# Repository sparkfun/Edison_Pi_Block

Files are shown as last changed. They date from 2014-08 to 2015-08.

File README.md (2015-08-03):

SparkFun Edison Pi Block
========================

SparkFun Edison Pi Block

[*SparkFun Edison Pi Block (DEV-13044)*](https://www.sparkfun.com/products/13044)

The Pi Block is a simple breakout board to bring the GPIO from the Intel Edison to the user. The Block provides level-shifted access to basic GPIO, PWM, UART, I<sup>2</sup>C, and SPI. The pins are presented in the same configuration as a [Raspberry Pi Model B header](http://elinux.org/RPi_Low-level_peripherals#Model_A_and_B_.28Original.29).

Access to the GPIO pins can be accomplished through [MRAA](https://github.com/intel-iot-devkit/mraa). The GPIO number listed on the board or Linux is not the same as MRAA. Refer to the table to see which GPIO pin maps to which number in MRAA. 

*MRAA pin map table based on [Intel's IOT Dev Kit Repository](https://github.com/intel-iot-devkit/mraa/blob/master/docs/edison.md)*

*Pins on the Pi Block are denoted with a * after the GP number*

<table class="table table-bordered">
<thead><tr><th class="text-center" title="Field #1">Edison Pin (Linux)</th>
<th class="text-center" title="Field #2">Arduino Breakout</th>
<th class="text-center" title="Field #3">Mini Breakout</th>
<th class="text-center" title="Field #4">MRAA Number</th>
<th class="text-center" title="Field #5">Pinmode0</th>
<th class="text-center" title="Field #6">Pinmode1</th>
<th class="text-center" title="Field #7">Pinmode2</th>
</tr></thead>
<tbody><tr class="warning" align="center"><td>GP12*</td>
<td>3</td>
<td>J18-7 </td>
<td align="right">20</td>
<td>GPIO-12</td>
<td>PWM0</td>
<td> </td>
</tr>
<tr class="warning" align="center"><td>GP13*</td>
<td>5</td>
<td>J18-1 </td>
<td align="right">14</td>
<td>GPIO-13</td>
<td>PWM1</td>
<td> </td>
</tr>
<tr class="warning" align="center"><td>GP14*</td>
<td>A4</td>
<td>J19-9 </td>
<td align="right">36</td>
<td>GPIO-14</td>
<td> </td>
<td> </td>
</tr>
<tr align="center"><td>GP15</td>
<td> </td>
<td>J20-7 </td>
<td align="right">48</td>
<td>GPIO-15</td>
<td> </td>
<td> </td>
</tr>
<tr class="warning" align="center"><td>GP19*</td>
<td> </td>
<td>J18-6 </td>
<td align="right">19</td>
<td>GPIO-19</td>
<td>I2C-1-SCL</td>
<td> </td>
</tr>
<tr class="warning" align="center"><td>GP20*</td>
<td> </td>
<td>J17-8 </td>
<td align="right">7</td>
<td>GPIO-20</td>
<td>I2C-1-SDA</td>
<td> </td>
</tr>
<tr align="center"><td>GP27</td>
<td> </td>
<td>J17-7 </td>
<td align="right">6</td>
<td>GPIO-27</td>
<td>I2C-6-SCL</td>
<td> </td>
</tr>
<tr align="center"><td>GP28</td>
<td> </td>
<td>J17-9 </td>
<td align="right">8</td>
<td>GPIO-28</td>
<td>I2C-6-SDA</td>
<td> </td>
</tr>
<tr align="center"><td>GP40</td>
<td>13</td>
<td>J19-10 </td>
<td align="right">37</td>
<td>GPIO-40</td>
<td>SSP2_CLK</td>
<td> </td>
</tr>
<tr align="center"><td>GP41</td>
<td>10</td>
<td>J20-10 </td>
<td align="right">51</td>
<td>GPIO-41</td>
<td>SSP2_FS</td>
<td> </td>
</tr>
<tr align="center"><td>GP42</td>
<td>12</td>
<td>J20-9 </td>
<td align="right">50</td>
<td>GPIO-42</td>
<td>SSP2_RXD</td>
<td> </td>
</tr>
<tr align="center"><td>GP43</td>
<td>11</td>
<td>J19-11 </td>
<td align="right">38</td>
<td>GPIO-43</td>
<td>SSP2_TXD</td>
<td> </td>
</tr>
<tr class="warning" align="center"><td>GP44*</td>
<td>A0</td>
<td>J19-4 </td>
<td align="right">31</td>
<td>GPIO-44</td>
<td> </td>
<td> </td>
</tr>
<tr class="warning" align="center"><td>GP45*</td>
<td>A1</td>
<td>J20-4 </td>
<td align="right">45</td>
<td>GPIO-45</td>
<td> </td>
<td> </td>
</tr>
<tr class="warning" align="center"><td>GP46*</td>
<td>A2</td>
<td>J19-5 </td>
<td align="right">32</td>
<td>GPIO-46</td>
<td> </td>
<td> </td>
</tr>
<tr class="warning" align="center"><td>GP47*</td>
<td>A3</td>
<td>J20-5 </td>
<td align="right">46</td>
<td>GPIO-47</td>
<td> </td>
<td> </td>
</tr>
<tr class="warning" align="center"><td>GP48*</td>
<td>7</td>
<td>J19-6 </td>
<td align="right">33</td>
<td>GPIO-48</td>
<td> </td>
<td> </td>
</tr>
<tr align="center"><td>GP49</td>
<td>8</td>
<td>J20-6 </td>
<td align="right">47</td>
<td>GPIO-49</td>
<td> </td>
<td> </td>
</tr>
<tr align="center"><td>GP77</td>
<td> </td>
<td>J19-12 </td>
<td align="right">39</td>
<td>GPIO-77</td>
<td>SD</td>
<td> </td>
</tr>
<tr align="center"><td>GP78</td>
<td> </td>
<td>J20-11 </td>
<td align="right">52</td>
<td>GPIO-78</td>
<td>SD</td>
<td> </td>
</tr>
<tr align="center"><td>GP79</td>
<td> </td>
<td>J20-12 </td>
<td align="right">53</td>
<td>GPIO-79</td>
<td>SD</td>
<td> </td>
</tr>
<tr align="center"><td>GP80</td>
<td> </td>
<td>J20-13 </td>
<td align="right">54</td>
<td>GPIO-80</td>
<td>SD</td>
<td> </td>
</tr>
<tr align="center"><td>GP81</td>
<td> </td>
<td>J20-14 </td>
<td align="right">55</td>
<td>GPIO-81</td>
<td>SD</td>
<td> </td>
</tr>
<tr align="center"><td>GP82</td>
<td> </td>
<td>J19-13 </td>
<td align="right">40</td>
<td>GPIO-82</td>
<td>SD</td>
<td> </td>
</tr>
<tr align="center"><td>GP83</td>
<td> </td>
<td>J19-14 </td>
<td align="right">41</td>
<td>GPIO-83</td>
<td>SD</td>
<td> </td>
</tr>
<tr align="center"><td>GP84</td>
<td> </td>
<td>J20-8 </td>
<td align="right">49</td>
<td>GPIO-84</td>
<td>SD</td>
<td> </td>
</tr>
<tr class="warning" align="center"><td>GP109*</td>
<td> </td>
<td>J17-11 </td>
<td align="right">10</td>
<td>GPIO-109</td>
<td>SPI-5-SCK</td>
<td> </td>
</tr>
<tr class="warning" align="center"><td>GP110*</td>
<td> </td>
<td>J18-10 </td>
<td align="right">23</td>
<td>GPIO-110</td>
<td>SPI-5-CS0</td>
<td> </td>
</tr>
<tr class="warning" align="center"><td>GP111*</td>
<td> </td>
<td>J17-10 </td>
<td align="right">9</td>
<td>GPIO-111</td>
<td>SPI-5-CS1</td>
<td> </td>
</tr>
<tr class="warning" align="center"><td>GP114*</td>
<td> </td>
<td>J18-11 </td>
<td align="right">24</td>
<td>GPIO-114</td>
<td>SPI-5-MISO</td>
<td> </td>
</tr>
<tr class="warning" align="center"><td>GP115*</td>
<td> </td>
<td>J17-12 </td>
<td align="right">11</td>
<td>GPIO-115</td>
<td>SPI-5-MOSI</td>
<td> </td>
</tr>
<tr align="center"><td>GP128</td>
<td>2</td>
<td>J17-14 </td>
<td align="right">13</td>
<td>GPIO-128</td>
<td>UART-1-CTS</td>
<td> </td>
</tr>
<tr align="center"><td>GP129</td>
<td>4</td>
<td>J18-12 </td>
<td align="right">25</td>
<td>GPIO-129</td>
<td>UART-1-RTS</td>
<td> </td>
</tr>
<tr class="warning" align="center"><td>GP130*</td>
<td>0</td>
<td>J18-13 </td>
<td align="right">26</td>
<td>GPIO-130</td>
<td>UART-1-RX</td>
<td> </td>
</tr>
<tr class="warning" align="center"><td>GP131*</td>
<td>1</td>
<td>J19-8 </td>
<td align="right">35</td>
<td>GPIO-131</td>
<td>UART-1-TX</td>
<td> </td>
</tr>
<tr align="center"><td>GP134</td>
<td> </td>
<td>J20-3 </td>
<td align="right">44</td>
<td> </td>
<td> </td>
<td> </td>
</tr>
<tr align="center"><td>GP135</td>
<td> </td>
<td>J17-5 </td>
<td align="right">4</td>
<td>GPIO-135</td>
<td>UART</td>
<td> </td>
</tr>
<tr align="center"><td>GP165</td>
<td>A5</td>
<td>J18-2 </td>
<td align="right">15</td>
<td>GPIO-165</td>
<td> </td>
<td> </td>
</tr>
<tr align="center"><td>GP182</td>
<td>6</td>
<td>J17-1 </td>
<td align="right">0</td>
<td>GPIO-182</td>
<td>PWM2</td>
<td> </td>
</tr>
<tr align="center"><td>GP183</td>
<td>9</td>
<td>J18-8 </td>
<td align="right">21</td>
<td>GPIO-183</td>
<td>PWM3</td>
<td> </td>
</tr>
</tbody></table>

Repository Contents
-------------------
* **/Hardware** - Eagle PCB layout files
* **/Production** - Files to support SparkFun production

Documentation
--------------
* **[Hookup Guide](https://learn.sparkfun.com/tutorials/sparkfun-blocks-for-intel-edison---pi-block)** - Basic hookup guide

Product Versions
----------------
* [DEV-13044](https://www.sparkfun.com/products/13038)- Hardware version 1.0. 

Version History
---------------
* [V_1.0](https://github.com/sparkfun/Edison_Pi_Block/tree/V_1.0) - GitHub files version 1.0

License Information
-------------------

This product is _**open source**_! 

Please review the LICENSE.md file for license information. 

If you have any questions or concerns on licensing, please contact techsupport@sparkfun.com.

Distributed as-is; no warranty is given.

- Your friends at SparkFun.

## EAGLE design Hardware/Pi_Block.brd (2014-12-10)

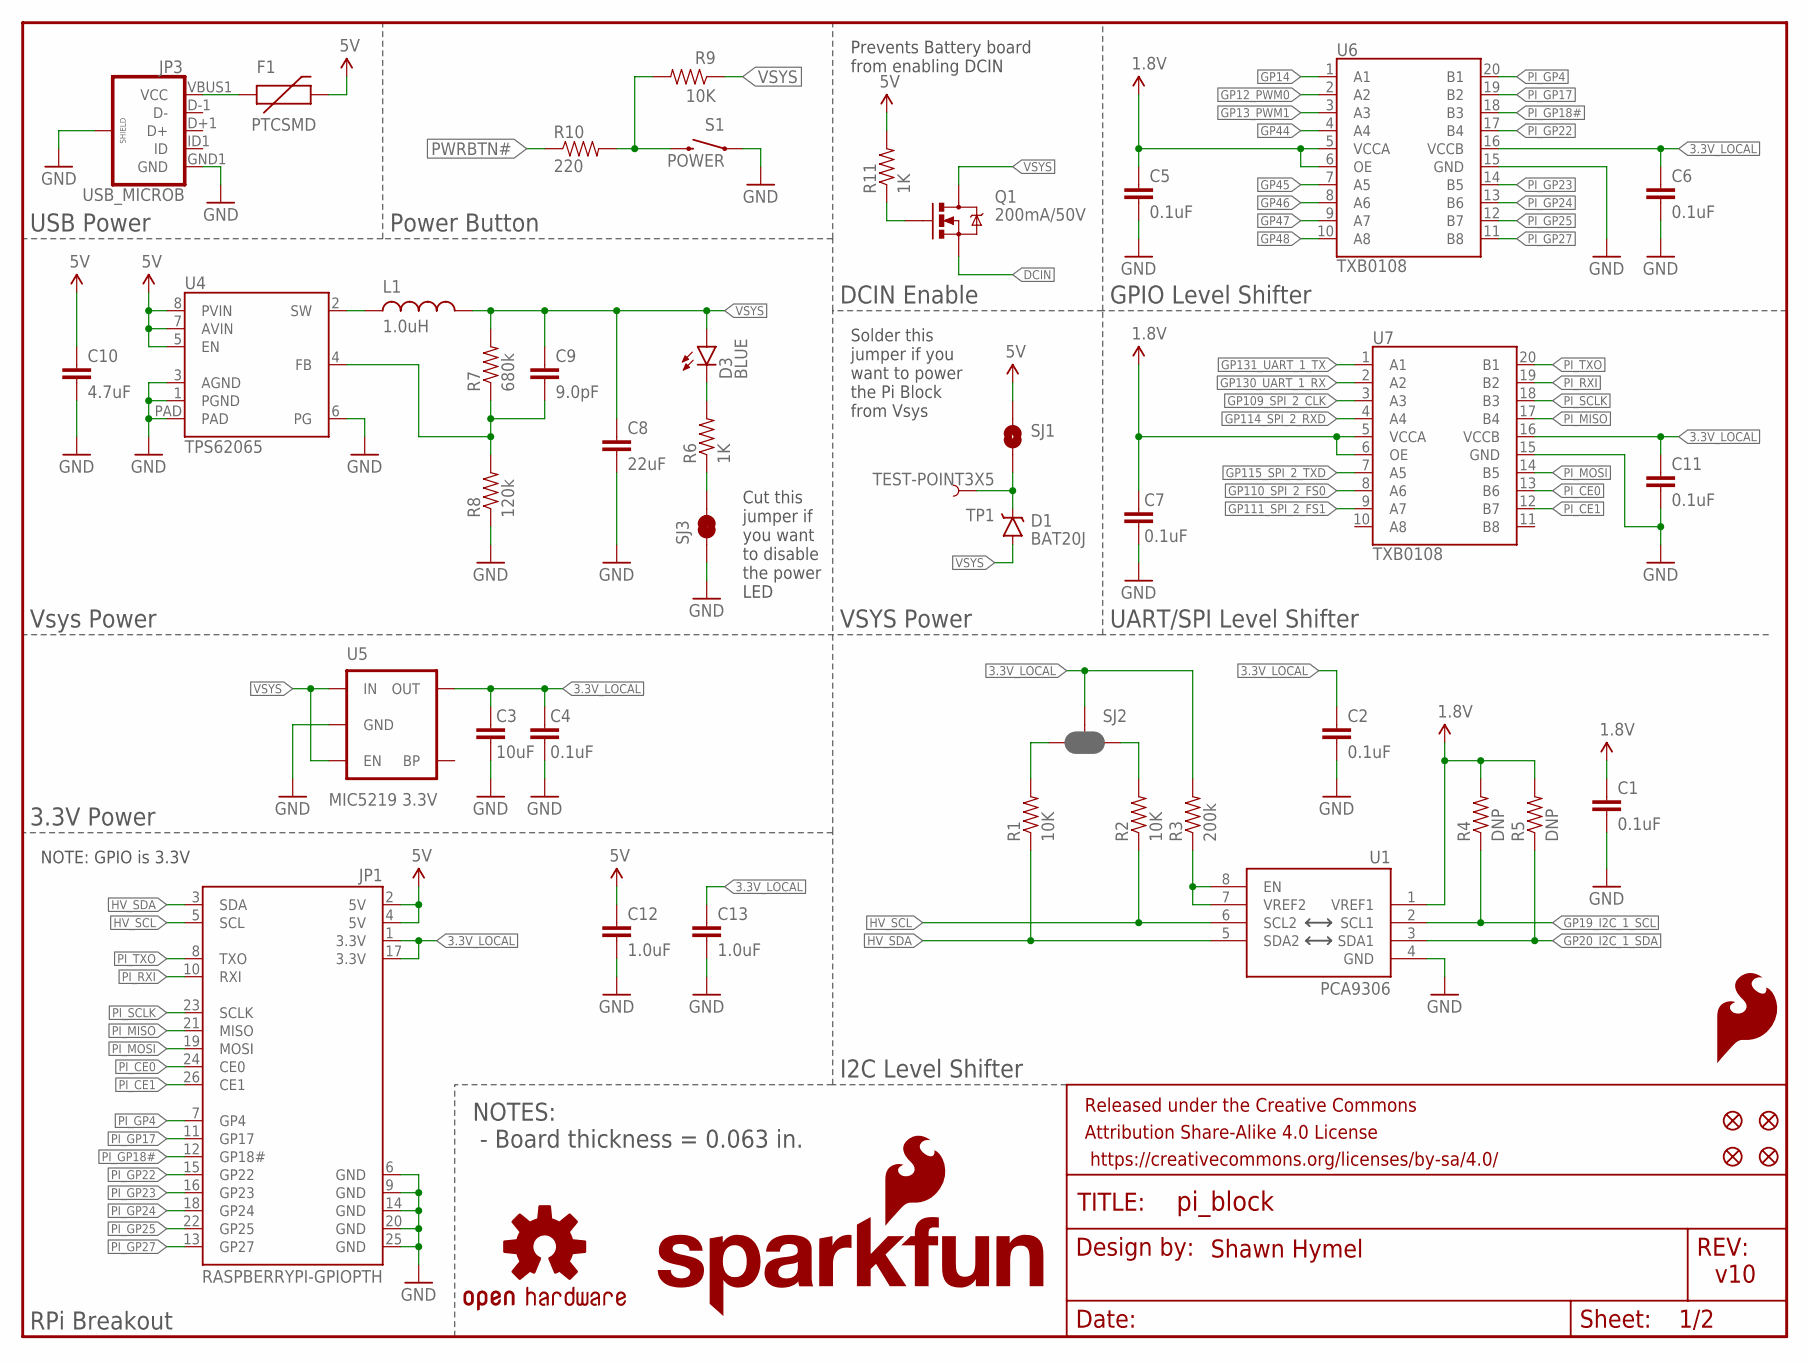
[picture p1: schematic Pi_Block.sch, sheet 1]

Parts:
C1, C2, C4, C5, C6, C7, C11: 0.1uF; 0603-CAP
C3: 10uF; 0805
C8: 22uF; 0805
C9: 9.0pF; 0603-CAP
C10: 4.7uF; 0603-CAP
C12, C13: 1.0uF; 0603-CAP
D1: BAT20J; SOD-323
D3: BLUE; LED-0603
F1: PTCSMD; PTC-1206
FID1, FID2, FID3, FID4: FIDUCIAL1X2; FIDUCIAL-1X2
FRAME1, FRAME3: FRAME-LETTER; CREATIVE_COMMONS
JP1: RASPBERRYPI-GPIOPTH; 2X13-SHROUDED
JP3: USB_MICROB; USB-B-MICRO-SMD_V03
L1: 1.0uH; INDUCTOR-SRP4020
LOGO1: OSHW-LOGOS; OSHW-LOGO-S
LOGO3: SFE_LOGO_FLAME.2_INCH; SFE_LOGO_FLAME_.2
LOGO4: SFE_LOGO_NAME_FLAME.1_INCH; SFE_LOGO_NAME_FLAME_.1
Q1: 200mA/50V; SOT23-3
R1, R2, R9: 10K; 0603-RES
R3: 200k; 0603-RES
R4, R5: DNP; 0603-RES
R6, R11: 1K; 0603-RES
R7: 680k; 0603-RES
R8: 120k; 0603-RES
R10: 220; 0603-RES
S1: POWER; TACTILE_SWITCH-SMD-RIGHT-ANGLE
SJ1: JUMPER-PAD-2-NOYES_SILK; PAD-JUMPER-2-NO_YES_SILK
SJ2: JUMPER-PAD-3-NC_BY_PASTE; PAD-JUMPER-3-NC_BY_PASTE_YES_SILK_FULL_BOX
SJ3: JUMPER-PAD-2-NC_BY_TRACE; PAD-JUMPER-2-NC_BY_TRACE_YES_SILK
TP1: TEST-POINT3X5; PAD.03X.05
U1: PCA9306; PCA9306DC-1:1
U4: TPS62065; WSON-8-PAD
U5: MIC5219 3.3V; SOT23-5
U6, U7: TXB0108; UFDFN-20

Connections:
1.8V: C1.1, C5.1, C7.1, R4.2, R5.2, U1.1 (VREF1), U6.5 (VCCA), U6.6 (OE), U7.5 (VCCA), U7.6 (OE); also elsewhere on the board
3.3V_LOCAL: C2.1, C3.1, C4.1, C6.1, C11.1, C13.1, JP1.1 (3.3V), JP1.17 (3.3V), R3.2, SJ2.2, U5.5 (OUT), U6.16 (VCCB), U7.16 (VCCB)
5V: C10.1, C12.1, F1.2, JP1.2 (5V), JP1.4 (5V), R11.2, SJ1.1, U4.5 (EN), U4.7 (AVIN), U4.8 (PVIN)
DCIN: Q1.2 (S); also elsewhere on the board
GND: C1.2, C2.2, C3.2, C4.2, C5.2, C6.2, C7.2, C8.2, C10.2, C11.2, C12.2, C13.2, JP1.6 (GND), JP1.9 (GND), JP1.14 (GND), JP1.20 (GND), JP1.25 (GND), JP3.GND1 (GND), JP3.SHIELD1 (SHIELD), JP3.SHIELD2 (SHIELD), JP3.SHIELD3 (SHIELD), R8.1, S1.1, SJ3.1, U1.4 (GND), U4.1 (PGND), U4.3 (AGND), U4.6 (PG), U4.PAD, U5.2 (GND), U6.15 (GND), U7.15 (GND); also elsewhere on the board
GP12_PWM0: U6.2 (A2); also elsewhere on the board
GP13_PWM1: U6.3 (A3); also elsewhere on the board
GP14: U6.1 (A1); also elsewhere on the board
GP19_I2C_1_SCL: R4.1, U1.2 (SCL1); also elsewhere on the board
GP20_I2C_1_SDA: R5.1, U1.3 (SDA1); also elsewhere on the board
GP44: U6.4 (A4); also elsewhere on the board
GP45: U6.7 (A5); also elsewhere on the board
GP46: U6.8 (A6); also elsewhere on the board
GP47: U6.9 (A7); also elsewhere on the board
GP48: U6.10 (A8); also elsewhere on the board
GP109_SPI_2_CLK: U7.3 (A3); also elsewhere on the board
GP110_SPI_2_FS0: U7.8 (A6); also elsewhere on the board
GP111_SPI_2_FS1: U7.9 (A7); also elsewhere on the board
GP114_SPI_2_RXD: U7.4 (A4); also elsewhere on the board
GP115_SPI_2_TXD: U7.7 (A5); also elsewhere on the board
GP130_UART_1_RX: U7.2 (A2); also elsewhere on the board
GP131_UART_1_TX: U7.1 (A1); also elsewhere on the board
HV_SCL: JP1.5 (SCL), R2.1, U1.6 (SCL2)
HV_SDA: JP1.3 (SDA), R1.1, U1.5 (SDA2)
unnamed: R3.1, U1.7 (VREF2), U1.8 (EN)
unnamed: F1.1, JP3.VBUS1 (VCC)
unnamed: D1.C, SJ1.2, TP1.P$1
unnamed: R1.2, SJ2.3
unnamed: R2.2, SJ2.1
unnamed: D3.C, R6.2
unnamed: R6.1, SJ3.2
unnamed: R9.2, R10.2, S1.2
unnamed: Q1.1 (G), R11.1
unnamed: C9.2, R7.1, R8.2, U4.4 (FB)
unnamed: L1.P$1 (1), U4.2 (SW)
PI_CE0: JP1.24 (CE0), U7.13 (B6)
PI_CE1: JP1.26 (CE1), U7.12 (B7)
PI_GP4: JP1.7 (GP4), U6.20 (B1)
PI_GP17: JP1.11 (GP17), U6.19 (B2)
PI_GP18#: JP1.12 (GP18#), U6.18 (B3)
PI_GP22: JP1.15 (GP22), U6.17 (B4)
PI_GP23: JP1.16 (GP23), U6.14 (B5)
PI_GP24: JP1.18 (GP24), U6.13 (B6)
PI_GP25: JP1.22 (GP25), U6.12 (B7)
PI_GP27: JP1.13 (GP27), U6.11 (B8)
PI_MISO: JP1.21 (MISO), U7.17 (B4)
PI_MOSI: JP1.19 (MOSI), U7.14 (B5)
PI_RXI: JP1.10 (RXI), U7.19 (B2)
PI_SCLK: JP1.23 (SCLK), U7.18 (B3)
PI_TXO: JP1.8 (TXO), U7.20 (B1)
PWRBTN#: R10.1; also elsewhere on the board
VSYS: C8.1, C9.1, D1.A, D3.A, L1.P$2 (2), Q1.3 (D), R7.2, R9.1, U5.1 (IN), U5.3 (EN); also elsewhere on the board

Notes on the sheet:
v10
Shawn Hymel
USB Power
Vsys Power
3.3V Power
RPi Breakout
GPIO Level Shifter
UART/SPI Level Shifter
I2C Level Shifter
Power Button
Prevents Battery board from enabling DCIN
DCIN Enable
VSYS Power
Solder this jumper if you want to power the Pi Block from Vsys
Cut this jumper if you want to disable the power LED
NOTE: GPIO is 3.3V
NOTES: - Board thickness = 0.063 in.

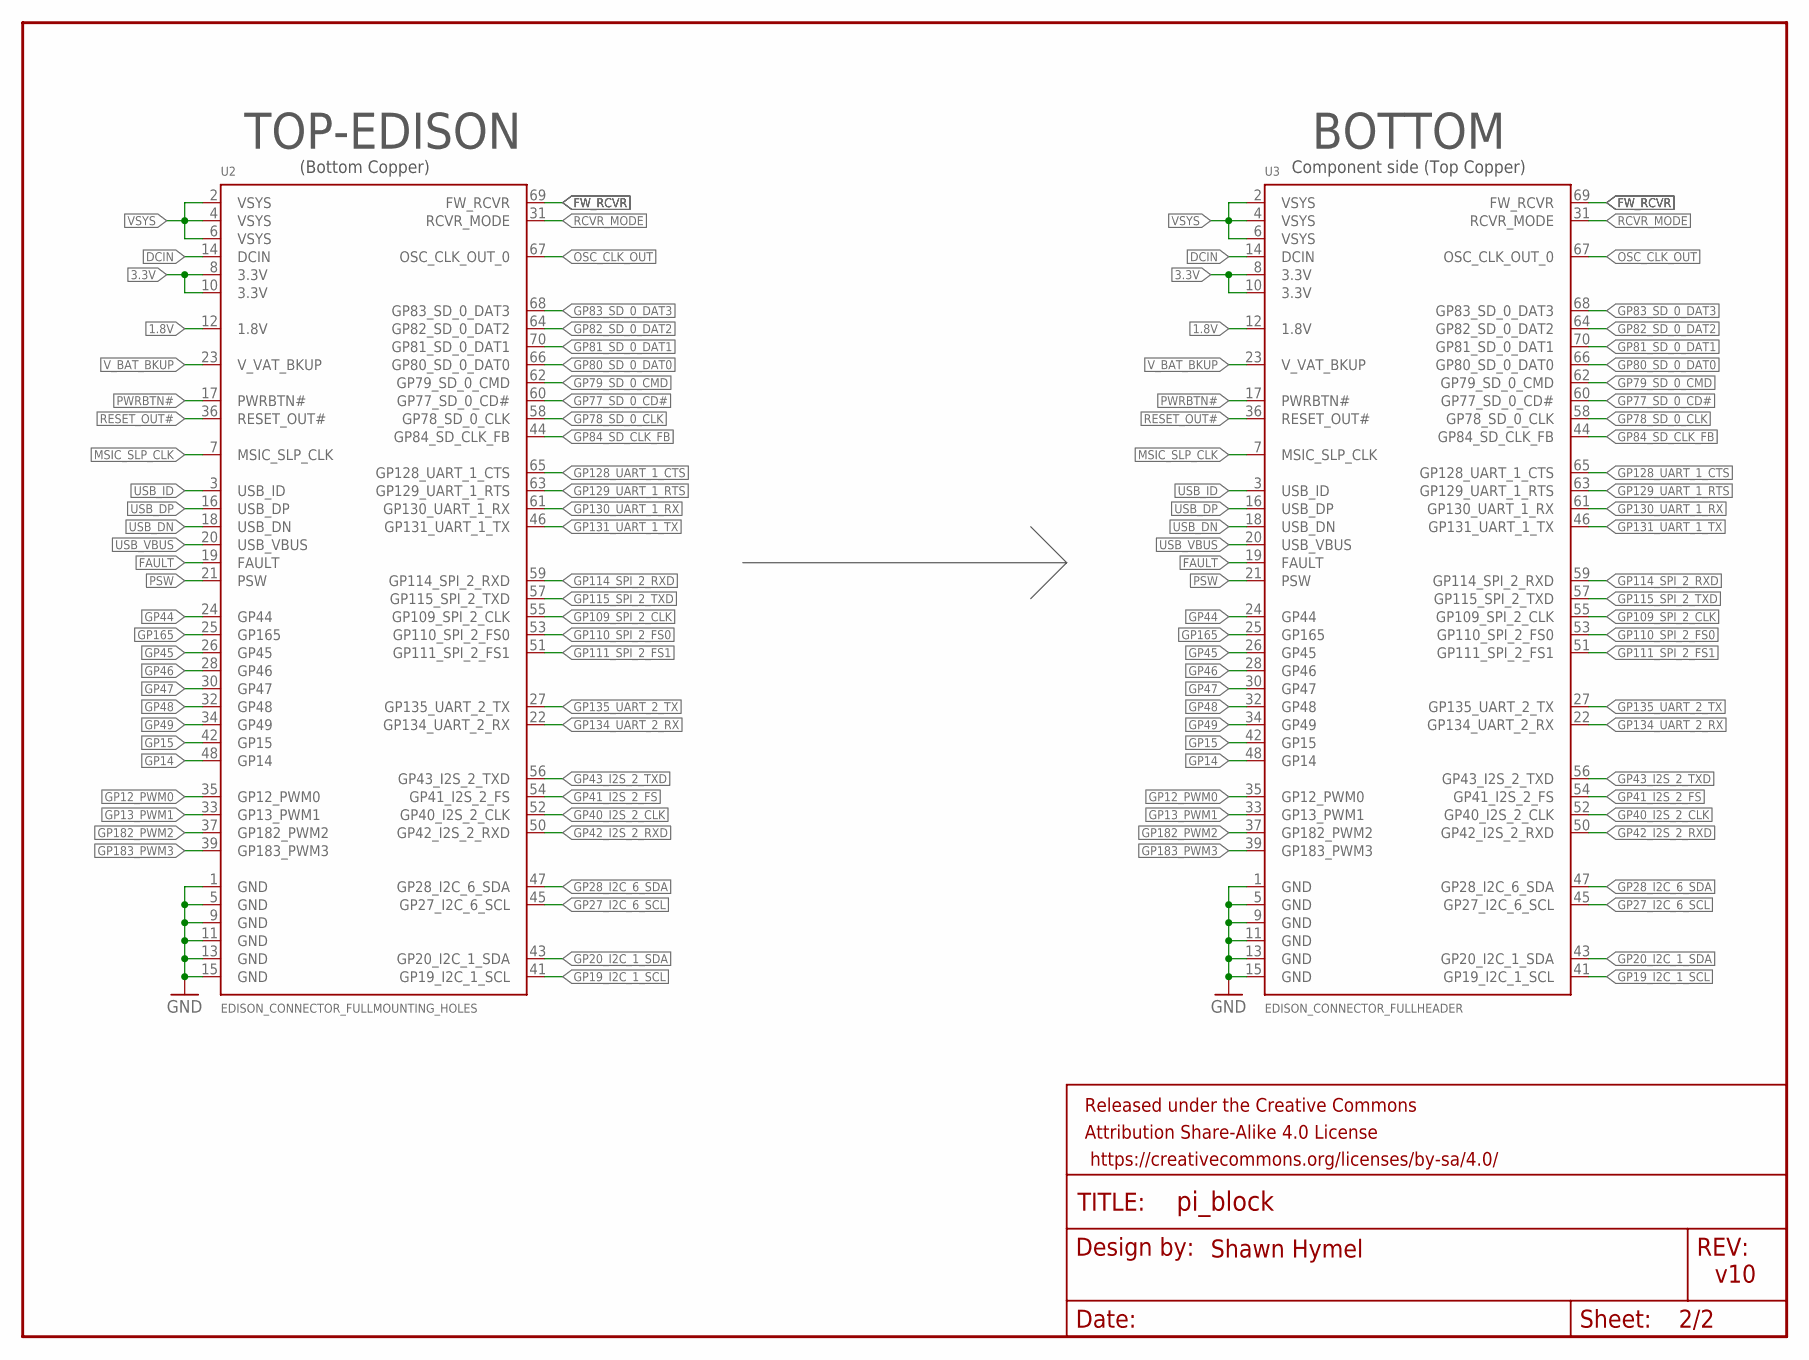
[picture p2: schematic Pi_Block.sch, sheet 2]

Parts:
FRAME2: FRAME-LETTER; CREATIVE_COMMONS
U2: EDISON_CONNECTOR_FULLMOUNTING_HOLES; EDISON_DAUGHTER
U3: EDISON_CONNECTOR_FULLHEADER; DF40C-70DP-0.4(51)

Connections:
1.8V: U2.12 (1.8V), U3.12 (1.8V); also elsewhere on the board
3.3V: U2.8 (3.3V), U2.10 (3.3V), U3.8 (3.3V), U3.10 (3.3V)
DCIN: U2.14 (DCIN), U3.14 (DCIN); also elsewhere on the board
FAULT: U2.19 (FAULT), U3.19 (FAULT)
FW_RCVR: U2.69 (FW_RCVR), U3.69 (FW_RCVR)
GND: U2.1 (GND), U2.5 (GND), U2.9 (GND), U2.11 (GND), U2.13 (GND), U2.15 (GND), U3.1 (GND), U3.5 (GND), U3.9 (GND), U3.11 (GND), U3.13 (GND), U3.15 (GND); also elsewhere on the board
GP12_PWM0: U2.35 (GP12_PWM0), U3.35 (GP12_PWM0); also elsewhere on the board
GP13_PWM1: U2.33 (GP13_PWM1), U3.33 (GP13_PWM1); also elsewhere on the board
GP14: U2.48 (GP14), U3.48 (GP14); also elsewhere on the board
GP15: U2.42 (GP15), U3.42 (GP15)
GP19_I2C_1_SCL: U2.41 (GP19_I2C_1_SCL), U3.41 (GP19_I2C_1_SCL); also elsewhere on the board
GP20_I2C_1_SDA: U2.43 (GP20_I2C_1_SDA), U3.43 (GP20_I2C_1_SDA); also elsewhere on the board
GP27_I2C_6_SCL: U2.45 (GP27_I2C_6_SCL), U3.45 (GP27_I2C_6_SCL)
GP28_I2C_6_SDA: U2.47 (GP28_I2C_6_SDA), U3.47 (GP28_I2C_6_SDA)
GP40_I2S_2_CLK: U2.52 (GP40_I2S_2_CLK), U3.52 (GP40_I2S_2_CLK)
GP41_I2S_2_FS: U2.54 (GP41_I2S_2_FS), U3.54 (GP41_I2S_2_FS)
GP42_I2S_2_RXD: U2.50 (GP42_I2S_2_RXD), U3.50 (GP42_I2S_2_RXD)
GP43_I2S_2_TXD: U2.56 (GP43_I2S_2_TXD), U3.56 (GP43_I2S_2_TXD)
GP44: U2.24 (GP44), U3.24 (GP44); also elsewhere on the board
GP45: U2.26 (GP45), U3.26 (GP45); also elsewhere on the board
GP46: U2.28 (GP46), U3.28 (GP46); also elsewhere on the board
GP47: U2.30 (GP47), U3.30 (GP47); also elsewhere on the board
GP48: U2.32 (GP48), U3.32 (GP48); also elsewhere on the board
GP49: U2.34 (GP49), U3.34 (GP49)
GP77_SD_0_CD#: U2.60 (GP77_SD_0_CD#), U3.60 (GP77_SD_0_CD#)
GP78_SD_0_CLK: U2.58 (GP78_SD_0_CLK), U3.58 (GP78_SD_0_CLK)
GP79_SD_0_CMD: U2.62 (GP79_SD_0_CMD), U3.62 (GP79_SD_0_CMD)
GP80_SD_0_DAT0: U2.66 (GP80_SD_0_DAT0), U3.66 (GP80_SD_0_DAT0)
GP81_SD_0_DAT1: U2.70 (GP81_SD_0_DAT1), U3.70 (GP81_SD_0_DAT1)
GP82_SD_0_DAT2: U2.64 (GP82_SD_0_DAT2), U3.64 (GP82_SD_0_DAT2)
GP83_SD_0_DAT3: U2.68 (GP83_SD_0_DAT3), U3.68 (GP83_SD_0_DAT3)
GP84_SD_CLK_FB: U2.44 (GP84_SD_CLK_FB), U3.44 (GP84_SD_CLK_FB)
GP109_SPI_2_CLK: U2.55 (GP109_SPI_2_CLK), U3.55 (GP109_SPI_2_CLK); also elsewhere on the board
GP110_SPI_2_FS0: U2.53 (GP110_SPI_2_FS0), U3.53 (GP110_SPI_2_FS0); also elsewhere on the board
GP111_SPI_2_FS1: U2.51 (GP111_SPI_2_FS1), U3.51 (GP111_SPI_2_FS1); also elsewhere on the board
GP114_SPI_2_RXD: U2.59 (GP114_SPI_2_RXD), U3.59 (GP114_SPI_2_RXD); also elsewhere on the board
GP115_SPI_2_TXD: U2.57 (GP115_SPI_2_TXD), U3.57 (GP115_SPI_2_TXD); also elsewhere on the board
GP128_UART_1_CTS: U2.65 (GP128_UART_1_CTS), U3.65 (GP128_UART_1_CTS)
GP129_UART_1_RTS: U2.63 (GP129_UART_1_RTS), U3.63 (GP129_UART_1_RTS)
GP130_UART_1_RX: U2.61 (GP130_UART_1_RX), U3.61 (GP130_UART_1_RX); also elsewhere on the board
GP131_UART_1_TX: U2.46 (GP131_UART_1_TX), U3.46 (GP131_UART_1_TX); also elsewhere on the board
GP134_UART_2_RX: U2.22 (GP134_UART_2_RX), U3.22 (GP134_UART_2_RX)
GP135_UART_2_TX: U2.27 (GP135_UART_2_TX), U3.27 (GP135_UART_2_TX)
GP165: U2.25 (GP165), U3.25 (GP165)
GP182_PWM2: U2.37 (GP182_PWM2), U3.37 (GP182_PWM2)
GP183_PWM3: U2.39 (GP183_PWM3), U3.39 (GP183_PWM3)
MSIC_SLP_CLK: U2.7 (MSIC_SLP_CLK), U3.7 (MSIC_SLP_CLK)
OSC_CLK_OUT: U2.67 (OSC_CLK_OUT_0), U3.67 (OSC_CLK_OUT_0)
PSW: U2.21 (PSW), U3.21 (PSW)
PWRBTN#: U2.17 (PWRBTN#), U3.17 (PWRBTN#); also elsewhere on the board
RCVR_MODE: U2.31 (RCVR_MODE), U3.31 (RCVR_MODE)
RESET_OUT#: U2.36 (RESET_OUT#), U3.36 (RESET_OUT#)
USB_DN: U2.18 (USB_DN), U3.18 (USB_DN)
USB_DP: U2.16 (USB_DP), U3.16 (USB_DP)
USB_ID: U2.3 (USB_ID), U3.3 (USB_ID)
USB_VBUS: U2.20 (USB_VBUS), U3.20 (USB_VBUS)
VSYS: U2.2 (VSYS), U2.4 (VSYS), U2.6 (VSYS), U3.2 (VSYS), U3.4 (VSYS), U3.6 (VSYS); also elsewhere on the board
V_BAT_BKUP: U2.23 (V_VAT_BKUP), U3.23 (V_VAT_BKUP)

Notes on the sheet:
TOP-EDISON
BOTTOM
Component side (Top Copper)
(Bottom Copper)
v10
Shawn Hymel

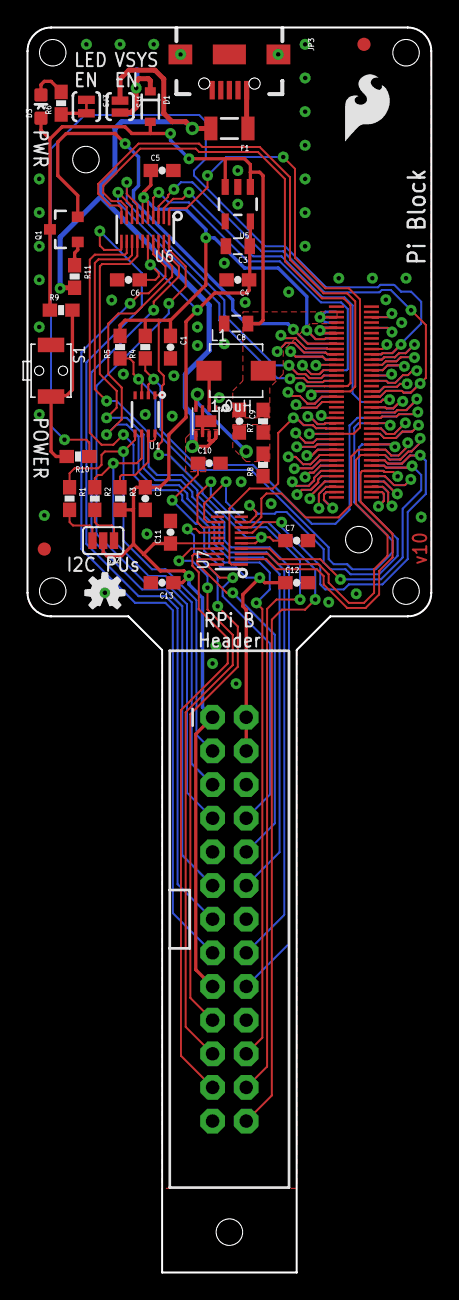
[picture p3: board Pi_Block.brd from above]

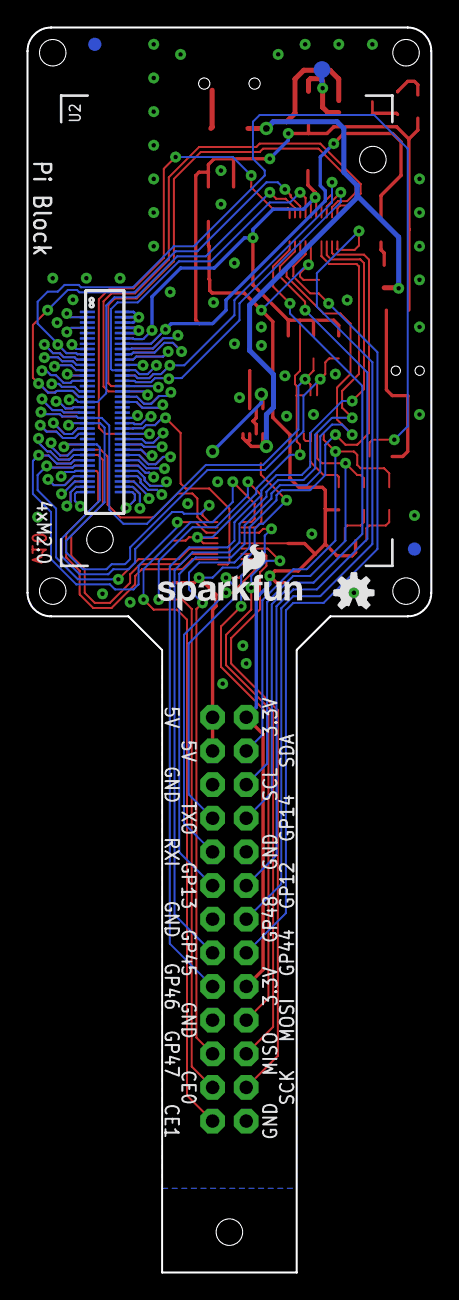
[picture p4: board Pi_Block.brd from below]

Board: 2 copper layers, 30.5 x 94.0 mm, 54 parts (7 on the bottom side), 88 nets.

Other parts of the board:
LOGO2: OSHW-LOGOS; OSHW-LOGO-S

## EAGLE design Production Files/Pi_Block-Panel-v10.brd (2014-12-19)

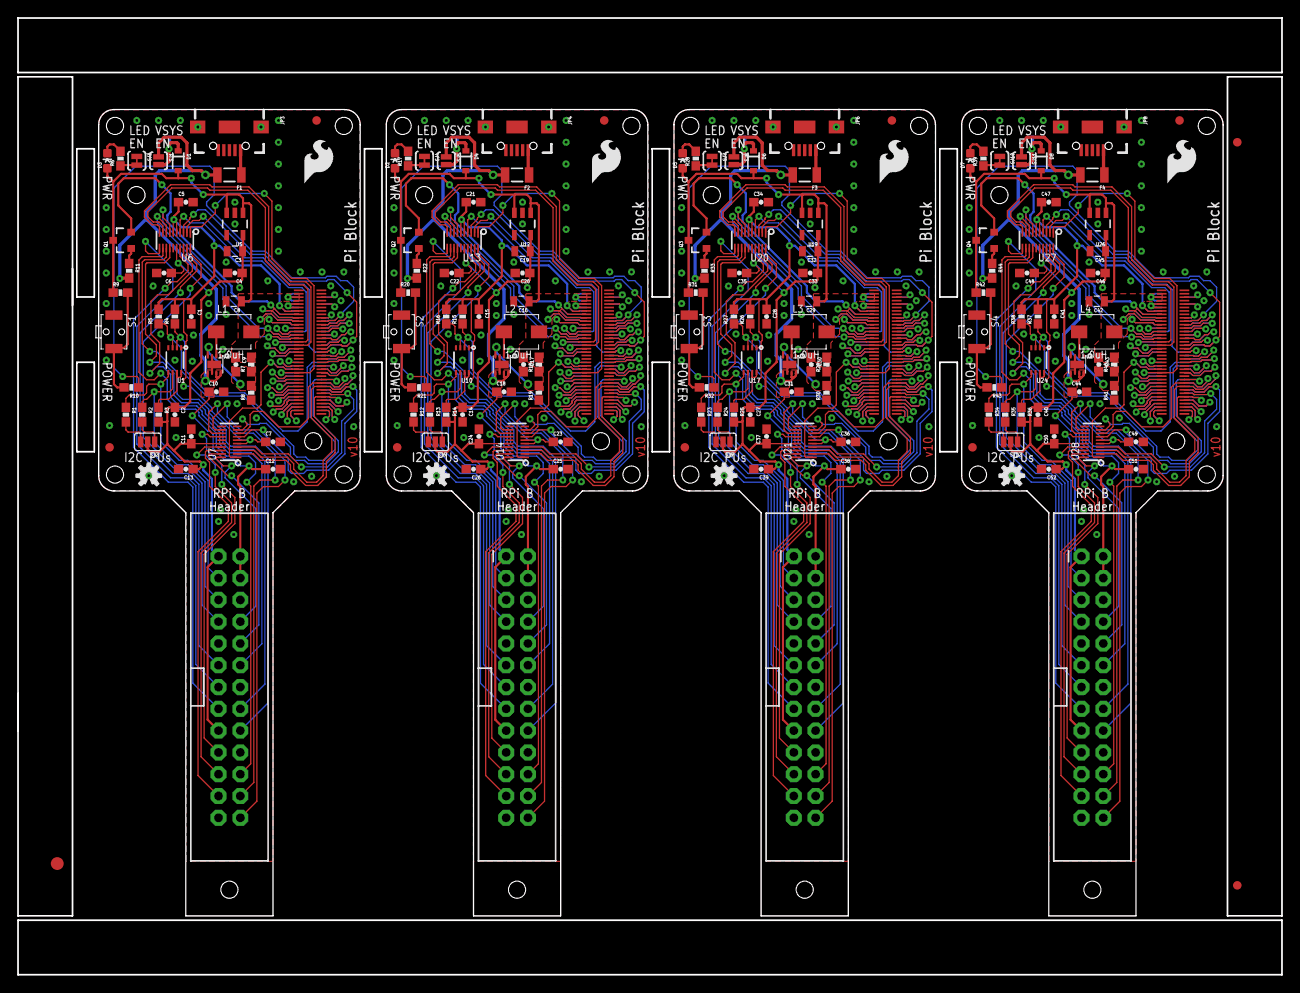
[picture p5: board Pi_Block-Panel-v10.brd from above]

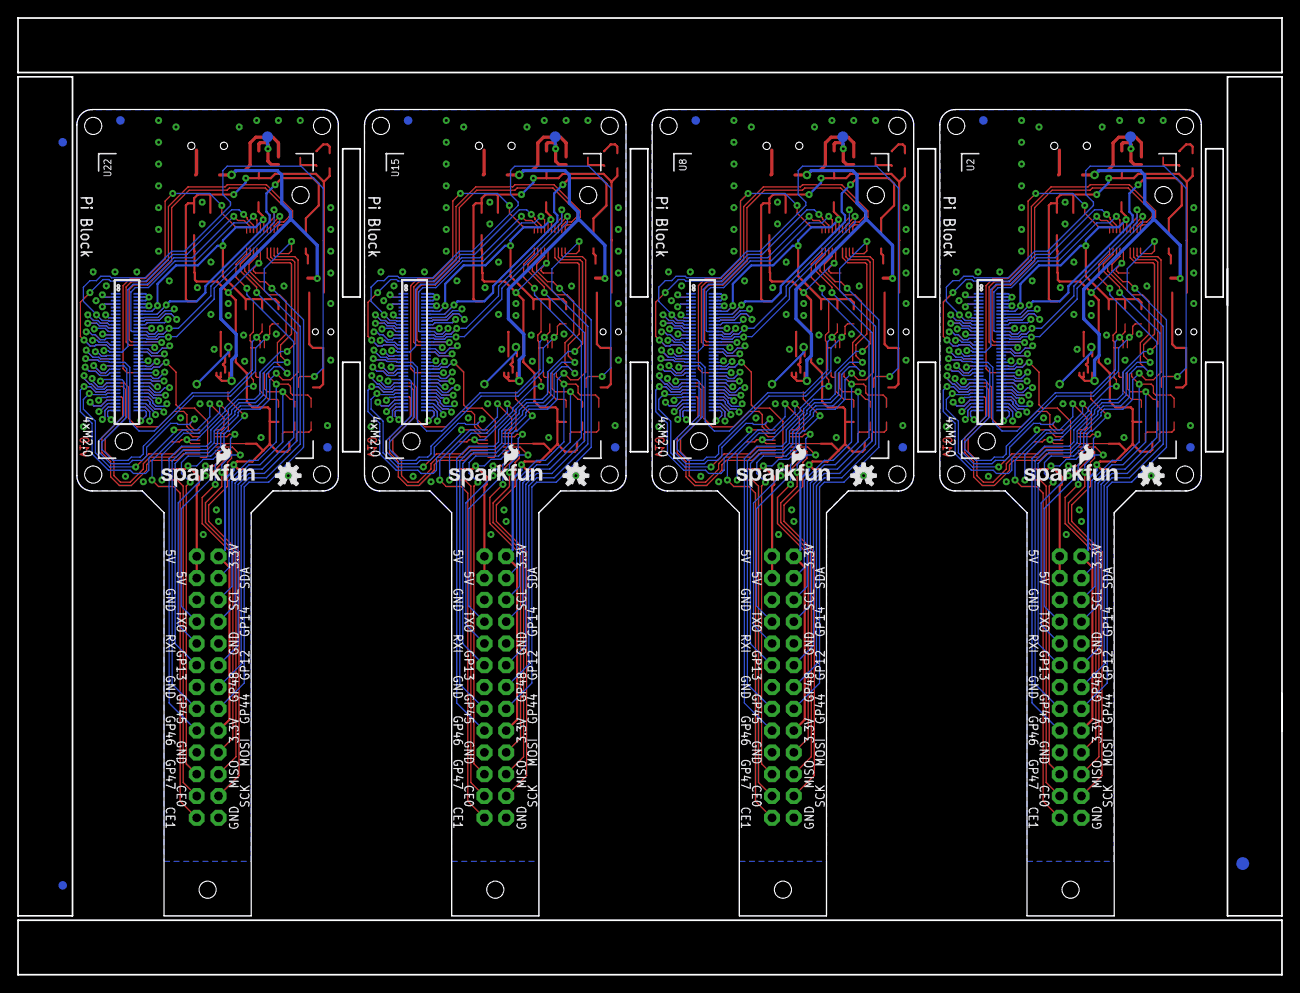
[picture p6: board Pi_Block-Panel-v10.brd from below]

Board: 2 copper layers, 147.3 x 111.5 mm, 210 parts (31 on the bottom side), 352 nets.

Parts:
C1, C2, C4, C5, C6, C7, C11, C14, C15, C20, C21, C22, C23, C24, C27, C28, C33, C34, C35, C36, C37, C40, C41, C46, C47, C48, C49, C50: 0.1uF; 0603-CAP
C3, C19, C32, C45: 10uF; 0805
C8, C16, C29, C42: 22uF; 0805
C9, C17, C30, C43: 9.0pF; 0603-CAP
C10, C18, C31, C44: 4.7uF; 0603-CAP
C12, C13, C25, C26, C38, C39, C51, C52: 1.0uF; 0603-CAP
D1, D4, D6, D8: BAT20J; SOD-323
D2, D3, D5, D7: BLUE; LED-0603
E$1, E$2: FIDUCIAL-1.5X3
E$3, E$4, E$5, E$6: FIDUCIAL-1X2
F1, F2, F3, F4: PTCSMD; PTC-1206
FID1, FID2, FID3, FID4, FID5, FID6, FID7, FID8, FID9, FID10, FID11, FID12, FID13, FID14, FID15, FID16: FIDUCIAL1X2; FIDUCIAL-1X2
JP1, JP2, JP5, JP7: RASPBERRYPI-GPIOPTH; 2X13-SHROUDED
JP3, JP4, JP6, JP8: USB_MICROB; USB-B-MICRO-SMD_V03
L1, L2, L3, L4: 1.0uH; INDUCTOR-SRP4020
LOGO1, LOGO2, LOGO5, LOGO6, LOGO9, LOGO10, LOGO13, LOGO14: OSHW-LOGOS; OSHW-LOGO-S
LOGO3, LOGO8, LOGO12, LOGO16: SFE_LOGO_FLAME.2_INCH; SFE_LOGO_FLAME_.2
LOGO4, LOGO7, LOGO11, LOGO15: SFE_LOGO_NAME_FLAME.1_INCH; SFE_LOGO_NAME_FLAME_.1
Q1, Q2, Q3, Q4: 200mA/50V; SOT23-3
R1, R2, R9, R12, R13, R20, R23, R24, R31, R34, R35, R42: 10K; 0603-RES
R3, R14, R25, R36: 200k; 0603-RES
R4, R5, R15, R16, R26, R27, R37, R38: DNP; 0603-RES
R6, R11, R17, R22, R28, R33, R39, R44: 1K; 0603-RES
R7, R18, R29, R40: 680k; 0603-RES
R8, R19, R30, R41: 120k; 0603-RES
R10, R21, R32, R43: 220; 0603-RES
S1, S2, S3, S4: POWER; TACTILE_SWITCH-SMD-RIGHT-ANGLE
SJ1, SJ5, SJ8, SJ11: JUMPER-PAD-2-NOYES_SILK; PAD-JUMPER-2-NO_YES_SILK
SJ2, SJ6, SJ9, SJ12: JUMPER-PAD-3-NC_BY_PASTE; PAD-JUMPER-3-NC_BY_PASTE_YES_SILK_FULL_BOX
SJ3, SJ4, SJ7, SJ10: JUMPER-PAD-2-NC_BY_TRACE; PAD-JUMPER-2-NC_BY_TRACE_YES_SILK
TP1, TP2, TP3, TP4: TEST-POINT3X5; PAD.03X.05
U1, U10, U17, U24: PCA9306; PCA9306DC-1:1
U2, U8, U15, U22: EDISON_CONNECTOR_FULLMOUNTING_HOLES; EDISON_DAUGHTER
U3, U9, U16, U23: EDISON_CONNECTOR_FULLHEADER; DF40C-70DP-0.4(51)
U4, U11, U18, U25: TPS62065; WSON-8-PAD
U5, U12, U19, U26: MIC5219 3.3V; SOT23-5
U6, U7, U13, U14, U20, U21, U27, U28: TXB0108; UFDFN-20

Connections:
1.8V: C1.1, C5.1, C7.1, R4.2, R5.2, U1.1, U2.12, U3.12, U6.5, U6.6, U7.5, U7.6
1.8V1: C15.1, C21.1, C23.1, R15.2, R16.2, U8.12, U9.12, U10.1, U13.5, U13.6, U14.5, U14.6
1.8V2: C28.1, C34.1, C36.1, R26.2, R27.2, U15.12, U16.12, U17.1, U20.5, U20.6, U21.5, U21.6
1.8V3: C41.1, C47.1, C49.1, R37.2, R38.2, U22.12, U23.12, U24.1, U27.5, U27.6, U28.5, U28.6
3.3V: U2.8, U2.10, U3.8, U3.10
3.3V1: U8.8, U8.10, U9.8, U9.10
3.3V2: U15.8, U15.10, U16.8, U16.10
3.3V3: U22.8, U22.10, U23.8, U23.10
3.3V_LOCAL: C2.1, C3.1, C4.1, C6.1, C11.1, C13.1, JP1.1, JP1.17, R3.2, SJ2.2, U5.5, U6.16, U7.16
3.3V_LOCAL1: C14.1, C19.1, C20.1, C22.1, C24.1, C26.1, JP2.1, JP2.17, R14.2, SJ6.2, U12.5, U13.16, U14.16
3.3V_LOCAL2: C27.1, C32.1, C33.1, C35.1, C37.1, C39.1, JP5.1, JP5.17, R25.2, SJ9.2, U19.5, U20.16, U21.16
3.3V_LOCAL3: C40.1, C45.1, C46.1, C48.1, C50.1, C52.1, JP7.1, JP7.17, R36.2, SJ12.2, U26.5, U27.16, U28.16
5V: C10.1, C12.1, F1.2, JP1.2, JP1.4, R11.2, SJ1.1, U4.5, U4.7, U4.8
5V1: C18.1, C25.1, F2.2, JP2.2, JP2.4, R22.2, SJ5.1, U11.5, U11.7, U11.8
5V2: C31.1, C38.1, F3.2, JP5.2, JP5.4, R33.2, SJ8.1, U18.5, U18.7, U18.8
5V3: C44.1, C51.1, F4.2, JP7.2, JP7.4, R44.2, SJ11.1, U25.5, U25.7, U25.8
DCIN: Q1.2, U2.14, U3.14
DCIN1: Q2.2, U8.14, U9.14
DCIN2: Q3.2, U15.14, U16.14
DCIN3: Q4.2, U22.14, U23.14
FAULT: U2.19, U3.19
FAULT1: U8.19, U9.19
FAULT2: U15.19, U16.19
FAULT3: U22.19, U23.19
FW_RCVR: U2.69, U3.69
FW_RCVR1: U8.69, U9.69
FW_RCVR2: U15.69, U16.69
FW_RCVR3: U22.69, U23.69
GND: C1.2, C2.2, C3.2, C4.2, C5.2, C6.2, C7.2, C8.2, C10.2, C11.2, C12.2, C13.2, JP1.6, JP1.9, JP1.14, JP1.20, JP1.25, JP3.GND1, JP3.SHIELD1, JP3.SHIELD2, JP3.SHIELD3, R8.1, S1.1, SJ3.1, U1.4, U2.1, U2.5, U2.9, U2.11, U2.13, U2.15, U3.1, U3.5, U3.9, U3.11, U3.13, U3.15, U4.1, U4.3, U4.6, U4.PAD, U5.2, U6.15, U7.15
GND1: C14.2, C15.2, C16.2, C18.2, C19.2, C20.2, C21.2, C22.2, C23.2, C24.2, C25.2, C26.2, JP2.6, JP2.9, JP2.14, JP2.20, JP2.25, JP4.GND1, JP4.SHIELD1, JP4.SHIELD2, JP4.SHIELD3, R19.1, S2.1, SJ4.1, U8.1, U8.5, U8.9, U8.11, U8.13, U8.15, U9.1, U9.5, U9.9, U9.11, U9.13, U9.15, U10.4, U11.1, U11.3, U11.6, U11.PAD, U12.2, U13.15, U14.15
GND2: C27.2, C28.2, C29.2, C31.2, C32.2, C33.2, C34.2, C35.2, C36.2, C37.2, C38.2, C39.2, JP5.6, JP5.9, JP5.14, JP5.20, JP5.25, JP6.GND1, JP6.SHIELD1, JP6.SHIELD2, JP6.SHIELD3, R30.1, S3.1, SJ7.1, U15.1, U15.5, U15.9, U15.11, U15.13, U15.15, U16.1, U16.5, U16.9, U16.11, U16.13, U16.15, U17.4, U18.1, U18.3, U18.6, U18.PAD, U19.2, U20.15, U21.15
GND3: C40.2, C41.2, C42.2, C44.2, C45.2, C46.2, C47.2, C48.2, C49.2, C50.2, C51.2, C52.2, JP7.6, JP7.9, JP7.14, JP7.20, JP7.25, JP8.GND1, JP8.SHIELD1, JP8.SHIELD2, JP8.SHIELD3, R41.1, S4.1, SJ10.1, U22.1, U22.5, U22.9, U22.11, U22.13, U22.15, U23.1, U23.5, U23.9, U23.11, U23.13, U23.15, U24.4, U25.1, U25.3, U25.6, U25.PAD, U26.2, U27.15, U28.15
GP1: U8.48, U9.48, U13.1
GP2: U8.42, U9.42
GP3: U8.34, U9.34
GP4: U8.32, U9.32, U13.10
GP5: U8.30, U9.30, U13.9
GP6: U8.28, U9.28, U13.8
GP7: U8.26, U9.26, U13.7
GP8: U8.25, U9.25
GP9: U8.24, U9.24, U13.4
GP10: U15.48, U16.48, U20.1
GP11: U15.42, U16.42
GP12: U15.34, U16.34
GP12_PWM0: U2.35, U3.35, U6.2
GP12_PWM1: U8.35, U9.35, U13.2
GP12_PWM2: U15.35, U16.35, U20.2
GP12_PWM3: U22.35, U23.35, U27.2
GP13: U15.32, U16.32, U20.10
GP13_PWM1: U2.33, U3.33, U6.3
GP13_PWM2: U8.33, U9.33, U13.3
GP13_PWM3: U15.33, U16.33, U20.3
GP13_PWM4: U22.33, U23.33, U27.3
GP14: U2.48, U3.48, U6.1
GP15: U2.42, U3.42
GP16: U15.30, U16.30, U20.9
GP17: U15.28, U16.28, U20.8
GP18: U15.26, U16.26, U20.7
GP19: U15.25, U16.25
GP19_I2C_1_SCL: R4.1, U1.2, U2.41, U3.41
GP19_I2C_1_SCL1: R15.1, U8.41, U9.41, U10.2
GP19_I2C_1_SCL2: R26.1, U15.41, U16.41, U17.2
GP19_I2C_1_SCL3: R37.1, U22.41, U23.41, U24.2
GP20: U15.24, U16.24, U20.4
GP20_I2C_1_SDA: R5.1, U1.3, U2.43, U3.43
GP20_I2C_1_SDA1: R16.1, U8.43, U9.43, U10.3
GP20_I2C_1_SDA2: R27.1, U15.43, U16.43, U17.3
GP20_I2C_1_SDA3: R38.1, U22.43, U23.43, U24.3
GP21: U22.48, U23.48, U27.1
GP22: U22.42, U23.42
GP23: U22.34, U23.34
GP24: U22.32, U23.32, U27.10
GP25: U22.30, U23.30, U27.9
GP26: U22.28, U23.28, U27.8
GP27: U22.26, U23.26, U27.7
GP27_I2C_6_SCL: U2.45, U3.45
GP27_I2C_6_SCL1: U8.45, U9.45
GP27_I2C_6_SCL2: U15.45, U16.45
GP27_I2C_6_SCL3: U22.45, U23.45
GP28: U22.25, U23.25
GP28_I2C_6_SDA: U2.47, U3.47
GP28_I2C_6_SDA1: U8.47, U9.47
GP28_I2C_6_SDA2: U15.47, U16.47
GP28_I2C_6_SDA3: U22.47, U23.47
GP29: U22.24, U23.24, U27.4
GP40_I2S_2_CLK: U2.52, U3.52
GP40_I2S_2_CLK1: U8.52, U9.52
GP40_I2S_2_CLK2: U15.52, U16.52
GP40_I2S_2_CLK3: U22.52, U23.52
GP41_I2S_2_FS: U2.54, U3.54
GP41_I2S_2_FS1: U8.54, U9.54
GP41_I2S_2_FS2: U15.54, U16.54
GP41_I2S_2_FS3: U22.54, U23.54
GP42_I2S_2_RXD: U2.50, U3.50
GP42_I2S_2_RXD1: U8.50, U9.50
GP42_I2S_2_RXD2: U15.50, U16.50
GP42_I2S_2_RXD3: U22.50, U23.50
GP43_I2S_2_TXD: U2.56, U3.56
GP43_I2S_2_TXD1: U8.56, U9.56
GP43_I2S_2_TXD2: U15.56, U16.56
GP43_I2S_2_TXD3: U22.56, U23.56
GP44: U2.24, U3.24, U6.4
GP45: U2.26, U3.26, U6.7
GP46: U2.28, U3.28, U6.8
GP47: U2.30, U3.30, U6.9
GP48: U2.32, U3.32, U6.10
GP49: U2.34, U3.34
GP77_SD_0_CD#: U2.60, U3.60
GP77_SD_0_CD#1: U8.60, U9.60
GP77_SD_0_CD#2: U15.60, U16.60
GP77_SD_0_CD#3: U22.60, U23.60
GP78_SD_0_CLK: U2.58, U3.58
GP78_SD_0_CLK1: U8.58, U9.58
GP78_SD_0_CLK2: U15.58, U16.58
GP78_SD_0_CLK3: U22.58, U23.58
GP79_SD_0_CMD: U2.62, U3.62
GP79_SD_0_CMD1: U8.62, U9.62
GP79_SD_0_CMD2: U15.62, U16.62
GP79_SD_0_CMD3: U22.62, U23.62
GP80_SD_0_DAT0: U2.66, U3.66
GP80_SD_0_DAT1: U8.66, U9.66
GP80_SD_0_DAT2: U15.66, U16.66
GP80_SD_0_DAT3: U22.66, U23.66
GP81_SD_0_DAT1: U2.70, U3.70
GP81_SD_0_DAT2: U8.70, U9.70
GP81_SD_0_DAT3: U15.70, U16.70
GP81_SD_0_DAT4: U22.70, U23.70
GP82_SD_0_DAT1: U8.64, U9.64
GP82_SD_0_DAT2: U2.64, U3.64
GP82_SD_0_DAT3: U15.64, U16.64
GP82_SD_0_DAT4: U22.64, U23.64
GP83_SD_0_DAT1: U8.68, U9.68
GP83_SD_0_DAT2: U15.68, U16.68
GP83_SD_0_DAT3: U2.68, U3.68
GP83_SD_0_DAT4: U22.68, U23.68
GP84_SD_CLK_FB: U2.44, U3.44
GP84_SD_CLK_FB1: U8.44, U9.44
GP84_SD_CLK_FB2: U15.44, U16.44
GP84_SD_CLK_FB3: U22.44, U23.44
GP109_SPI_2_CLK: U2.55, U3.55, U7.3
GP109_SPI_2_CLK1: U8.55, U9.55, U14.3
GP109_SPI_2_CLK2: U15.55, U16.55, U21.3
GP109_SPI_2_CLK3: U22.55, U23.55, U28.3
GP110_SPI_2_FS0: U2.53, U3.53, U7.8
GP110_SPI_2_FS1: U8.53, U9.53, U14.8
GP110_SPI_2_FS2: U15.53, U16.53, U21.8
GP110_SPI_2_FS3: U22.53, U23.53, U28.8
GP111_SPI_2_FS1: U2.51, U3.51, U7.9
GP111_SPI_2_FS2: U8.51, U9.51, U14.9
GP111_SPI_2_FS3: U15.51, U16.51, U21.9
GP111_SPI_2_FS4: U22.51, U23.51, U28.9
GP114_SPI_2_RXD: U2.59, U3.59, U7.4
GP114_SPI_2_RXD1: U8.59, U9.59, U14.4
GP114_SPI_2_RXD2: U15.59, U16.59, U21.4
GP114_SPI_2_RXD3: U22.59, U23.59, U28.4
GP115_SPI_2_TXD: U2.57, U3.57, U7.7
GP115_SPI_2_TXD1: U8.57, U9.57, U14.7
GP115_SPI_2_TXD2: U15.57, U16.57, U21.7
GP115_SPI_2_TXD3: U22.57, U23.57, U28.7
GP128_UART_1_CTS: U2.65, U3.65
GP128_UART_1_CTS1: U8.65, U9.65
GP128_UART_1_CTS2: U15.65, U16.65
GP128_UART_1_CTS3: U22.65, U23.65
GP129_UART_1_RTS: U2.63, U3.63
GP129_UART_1_RTS1: U8.63, U9.63
GP129_UART_1_RTS2: U15.63, U16.63
GP129_UART_1_RTS3: U22.63, U23.63
GP130_UART_1_RX: U2.61, U3.61, U7.2
GP130_UART_1_RX1: U8.61, U9.61, U14.2
GP130_UART_1_RX2: U15.61, U16.61, U21.2
GP130_UART_1_RX3: U22.61, U23.61, U28.2
GP131_UART_1_TX: U2.46, U3.46, U7.1
GP131_UART_1_TX1: U8.46, U9.46, U14.1
GP131_UART_1_TX2: U15.46, U16.46, U21.1
GP131_UART_1_TX3: U22.46, U23.46, U28.1
GP134_UART_2_RX: U2.22, U3.22
GP134_UART_2_RX1: U8.22, U9.22
GP134_UART_2_RX2: U15.22, U16.22
GP134_UART_2_RX3: U22.22, U23.22
GP135_UART_2_TX: U2.27, U3.27
GP135_UART_2_TX1: U8.27, U9.27
GP135_UART_2_TX2: U15.27, U16.27
GP135_UART_2_TX3: U22.27, U23.27
GP165: U2.25, U3.25
GP182_PWM1: U8.37, U9.37
GP182_PWM2: U2.37, U3.37
GP182_PWM3: U15.37, U16.37
GP182_PWM4: U22.37, U23.37
GP183_PWM1: U8.39, U9.39
GP183_PWM2: U15.39, U16.39
GP183_PWM3: U2.39, U3.39
GP183_PWM4: U22.39, U23.39
HV_SCL: JP1.5, R2.1, U1.6
HV_SCL1: JP2.5, R13.1, U10.6
HV_SCL2: JP5.5, R24.1, U17.6
HV_SCL3: JP7.5, R35.1, U24.6
HV_SDA: JP1.3, R1.1, U1.5
HV_SDA1: JP2.3, R12.1, U10.5
HV_SDA2: JP5.3, R23.1, U17.5
HV_SDA3: JP7.3, R34.1, U24.5
MSIC_SLP_CLK: U2.7, U3.7
MSIC_SLP_CLK1: U8.7, U9.7
MSIC_SLP_CLK2: U15.7, U16.7
MSIC_SLP_CLK3: U22.7, U23.7
unnamed: R3.1, U1.7, U1.8
unnamed: F1.1, JP3.VBUS1
unnamed: D1.C, SJ1.2, TP1.P$1
unnamed: R1.2, SJ2.3
unnamed: R2.2, SJ2.1
unnamed: R14.1, U10.7, U10.8
unnamed: F2.1, JP4.VBUS1
unnamed: D2.C, R17.2
unnamed: R17.1, SJ4.2
unnamed: C17.2, R18.1, R19.2, U11.4
unnamed: L2.P$1, U11.2
unnamed: D3.C, R6.2
unnamed: R6.1, SJ3.2
unnamed: R20.2, R21.2, S2.2
unnamed: R9.2, R10.2, S1.2
unnamed: Q1.1, R11.1
unnamed: Q2.1, R22.1
unnamed: C9.2, R7.1, R8.2, U4.4
unnamed: L1.P$1, U4.2
unnamed: D4.C, SJ5.2, TP2.P$1
unnamed: R12.2, SJ6.3
unnamed: R13.2, SJ6.1
unnamed: R25.1, U17.7, U17.8
unnamed: F3.1, JP6.VBUS1
unnamed: D5.C, R28.2
unnamed: R28.1, SJ7.2
unnamed: C30.2, R29.1, R30.2, U18.4
unnamed: L3.P$1, U18.2
unnamed: R31.2, R32.2, S3.2
unnamed: Q3.1, R33.1
unnamed: D6.C, SJ8.2, TP3.P$1
unnamed: R23.2, SJ9.3
unnamed: R24.2, SJ9.1
unnamed: R36.1, U24.7, U24.8
unnamed: F4.1, JP8.VBUS1
unnamed: D7.C, R39.2
unnamed: R39.1, SJ10.2
unnamed: C43.2, R40.1, R41.2, U25.4
unnamed: L4.P$1, U25.2
unnamed: R42.2, R43.2, S4.2
unnamed: Q4.1, R44.1
unnamed: D8.C, SJ11.2, TP4.P$1
unnamed: R34.2, SJ12.3
unnamed: R35.2, SJ12.1
OSC_CLK_OUT: U2.67, U3.67
OSC_CLK_OUT1: U8.67, U9.67
OSC_CLK_OUT2: U15.67, U16.67
OSC_CLK_OUT3: U22.67, U23.67
PI_CE0: JP1.24, U7.13
PI_CE1: JP1.26, U7.12
PI_CE2: JP2.24, U14.13
PI_CE3: JP2.26, U14.12
PI_CE4: JP5.24, U21.13
PI_CE5: JP5.26, U21.12
PI_CE6: JP7.24, U28.13
PI_CE7: JP7.26, U28.12
PI_GP1: JP2.7, U13.20
PI_GP2: JP2.11, U13.19
PI_GP3: JP2.15, U13.17
PI_GP4: JP1.7, U6.20
PI_GP5: JP2.16, U13.14
PI_GP6: JP2.18, U13.13
PI_GP7: JP2.22, U13.12
PI_GP8: JP2.13, U13.11
PI_GP9: JP5.7, U20.20
PI_GP10: JP5.11, U20.19
PI_GP11: JP5.15, U20.17
PI_GP12: JP5.16, U20.14
PI_GP13: JP5.18, U20.13
PI_GP14: JP5.22, U20.12
PI_GP15: JP5.13, U20.11
PI_GP16: JP7.7, U27.20
PI_GP17: JP1.11, U6.19
PI_GP18: JP7.11, U27.19
PI_GP18#: JP1.12, U6.18
PI_GP18#1: JP2.12, U13.18
PI_GP18#2: JP5.12, U20.18
PI_GP18#3: JP7.12, U27.18
PI_GP19: JP7.15, U27.17
PI_GP20: JP7.16, U27.14
PI_GP21: JP7.18, U27.13
PI_GP22: JP1.15, U6.17
PI_GP23: JP1.16, U6.14
PI_GP24: JP1.18, U6.13
PI_GP25: JP1.22, U6.12
PI_GP26: JP7.22, U27.12
PI_GP27: JP1.13, U6.11
PI_GP28: JP7.13, U27.11
PI_MISO: JP1.21, U7.17
PI_MISO1: JP2.21, U14.17
PI_MISO2: JP5.21, U21.17
PI_MISO3: JP7.21, U28.17
PI_MOSI: JP1.19, U7.14
PI_MOSI1: JP2.19, U14.14
PI_MOSI2: JP5.19, U21.14
PI_MOSI3: JP7.19, U28.14
PI_RXI: JP1.10, U7.19
PI_RXI1: JP2.10, U14.19
PI_RXI2: JP5.10, U21.19
PI_RXI3: JP7.10, U28.19
PI_SCLK: JP1.23, U7.18
PI_SCLK1: JP2.23, U14.18
PI_SCLK2: JP5.23, U21.18
PI_SCLK3: JP7.23, U28.18
PI_TXO: JP1.8, U7.20
PI_TXO1: JP2.8, U14.20
PI_TXO2: JP5.8, U21.20
PI_TXO3: JP7.8, U28.20
PSW: U2.21, U3.21
PSW1: U8.21, U9.21
PSW2: U15.21, U16.21
PSW3: U22.21, U23.21
PWRBTN#: R10.1, U2.17, U3.17
PWRBTN#1: R21.1, U8.17, U9.17
PWRBTN#2: R32.1, U15.17, U16.17
PWRBTN#3: R43.1, U22.17, U23.17
RCVR_MODE: U2.31, U3.31
RCVR_MODE1: U8.31, U9.31
RCVR_MODE2: U15.31, U16.31
RCVR_MODE3: U22.31, U23.31
RESET_OUT#: U2.36, U3.36
RESET_OUT#1: U8.36, U9.36
RESET_OUT#2: U15.36, U16.36
RESET_OUT#3: U22.36, U23.36
USB_DN: U2.18, U3.18
USB_DN1: U8.18, U9.18
USB_DN2: U15.18, U16.18
USB_DN3: U22.18, U23.18
USB_DP: U2.16, U3.16
USB_DP1: U8.16, U9.16
USB_DP2: U15.16, U16.16
USB_DP3: U22.16, U23.16
USB_ID: U2.3, U3.3
USB_ID1: U8.3, U9.3
USB_ID2: U15.3, U16.3
USB_ID3: U22.3, U23.3
USB_VBUS: U2.20, U3.20
USB_VBUS1: U8.20, U9.20
USB_VBUS2: U15.20, U16.20
USB_VBUS3: U22.20, U23.20
VSYS: C8.1, C9.1, D1.A, D3.A, L1.P$2, Q1.3, R7.2, R9.1, U2.2, U2.4, U2.6, U3.2, U3.4, U3.6, U5.1, U5.3
VSYS1: C16.1, C17.1, D2.A, D4.A, L2.P$2, Q2.3, R18.2, R20.1, U8.2, U8.4, U8.6, U9.2, U9.4, U9.6, U12.1, U12.3
VSYS2: C29.1, C30.1, D5.A, D6.A, L3.P$2, Q3.3, R29.2, R31.1, U15.2, U15.4, U15.6, U16.2, U16.4, U16.6, U19.1, U19.3
VSYS3: C42.1, C43.1, D7.A, D8.A, L4.P$2, Q4.3, R40.2, R42.1, U22.2, U22.4, U22.6, U23.2, U23.4, U23.6, U26.1, U26.3
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

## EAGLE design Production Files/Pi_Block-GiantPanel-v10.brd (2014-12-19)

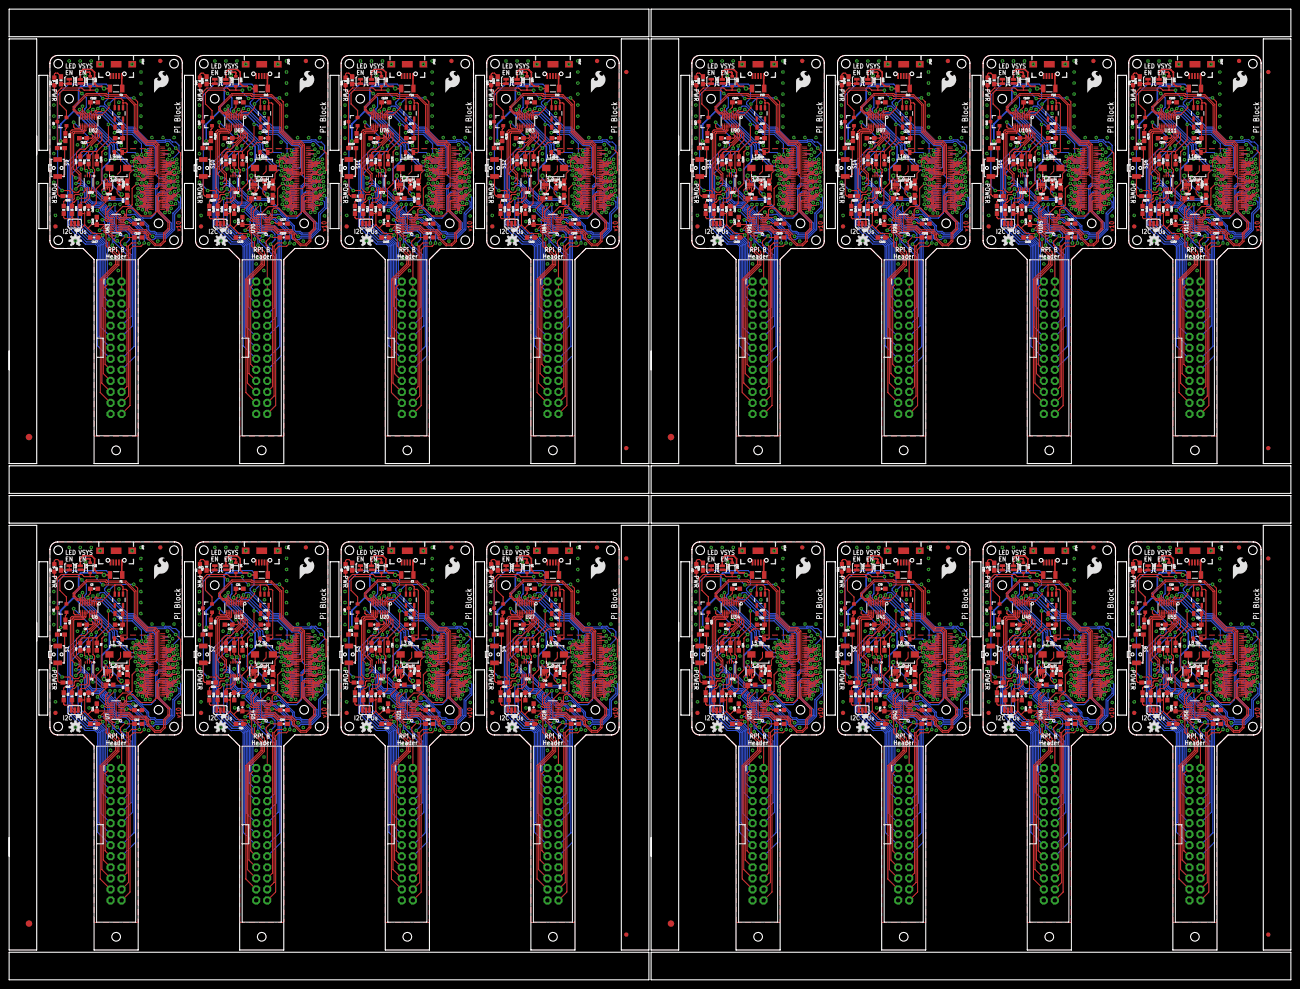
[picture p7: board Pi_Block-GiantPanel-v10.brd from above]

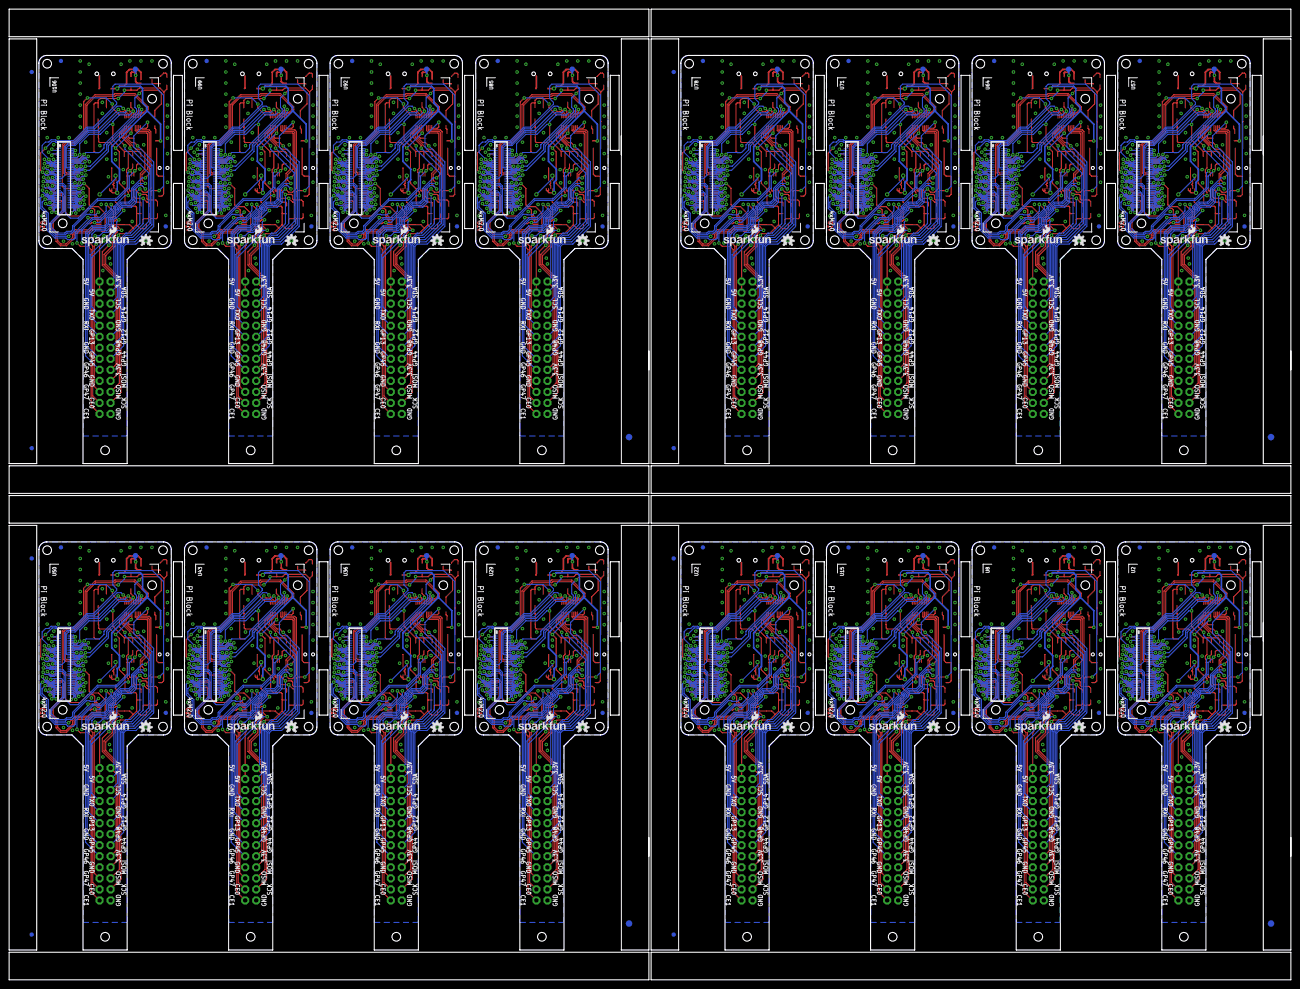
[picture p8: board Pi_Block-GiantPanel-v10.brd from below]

Board: 2 copper layers, 295.1 x 223.5 mm, 840 parts (124 on the bottom side), 1408 nets.

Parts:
C1, C2, C4, C5, C6, C7, C11, C14, C15, C20, C21, C22, C23, C24, C27, C28, C33, C34, C35, C36, C37, C40, C41, C46, C47, C48, C49, C50, C53, C54, C59, C60, C61, C62, C63, C66, C67, C72, C73, C74, C75, C76, C79, C80, C85, C86, C87, C88, C89, C92, C93, C98, C99, C100, C101, C102, C105, C106, C111, C112, C113, C114, C115, C118, C119, C124, C125, C126, C127, C128, C131, C132, C137, C138, C139, C140, C141, C144, C145, C150, C151, C152, C153, C154, C157, C158, C163, C164, C165, C166, C167, C170, C171, C176, C177, C178, C179, C180, C183, C184, C189, C190, C191, C192, C193, C196, C197, C202, C203, C204, C205, C206: 0.1uF; 0603-CAP
C3, C19, C32, C45, C58, C71, C84, C97, C110, C123, C136, C149, C162, C175, C188, C201: 10uF; 0805
C8, C16, C29, C42, C55, C68, C81, C94, C107, C120, C133, C146, C159, C172, C185, C198: 22uF; 0805
C9, C17, C30, C43, C56, C69, C82, C95, C108, C121, C134, C147, C160, C173, C186, C199: 9.0pF; 0603-CAP
C10, C18, C31, C44, C57, C70, C83, C96, C109, C122, C135, C148, C161, C174, C187, C200: 4.7uF; 0603-CAP
C12, C13, C25, C26, C38, C39, C51, C52, C64, C65, C77, C78, C90, C91, C103, C104, C116, C117, C129, C130, C142, C143, C155, C156, C168, C169, C181, C182, C194, C195, C207, C208: 1.0uF; 0603-CAP
D1, D4, D6, D8, D10, D12, D14, D16, D18, D20, D22, D24, D26, D28, D30, D32: BAT20J; SOD-323
D2, D3, D5, D7, D9, D11, D13, D15, D17, D19, D21, D23, D25, D27, D29, D31: BLUE; LED-0603
E$1, E$2, E$9, E$10, E$15, E$16, E$21, E$22: FIDUCIAL-1.5X3
E$3, E$4, E$5, E$6, E$7, E$8, E$11, E$12, E$13, E$14, E$17, E$18, E$19, E$20, E$23, E$24: FIDUCIAL-1X2
F1, F2, F3, F4, F5, F6, F7, F8, F9, F10, F11, F12, F13, F14, F15, F16: PTCSMD; PTC-1206
FID1, FID2, FID3, FID4, FID5, FID6, FID7, FID8, FID9, FID10, FID11, FID12, FID13, FID14, FID15, FID16, FID17, FID18, FID19, FID20, FID21, FID22, FID23, FID24, FID25, FID26, FID27, FID28, FID29, FID30, FID31, FID32, FID33, FID34, FID35, FID36, FID37, FID38, FID39, FID40, FID41, FID42, FID43, FID44, FID45, FID46, FID47, FID48, FID49, FID50, FID51, FID52, FID53, FID54, FID55, FID56, FID57, FID58, FID59, FID60, FID61, FID62, FID63, FID64: FIDUCIAL1X2; FIDUCIAL-1X2
JP1, JP2, JP5, JP7, JP9, JP11, JP13, JP15, JP17, JP19, JP21, JP23, JP25, JP27, JP29, JP31: RASPBERRYPI-GPIOPTH; 2X13-SHROUDED
JP3, JP4, JP6, JP8, JP10, JP12, JP14, JP16, JP18, JP20, JP22, JP24, JP26, JP28, JP30, JP32: USB_MICROB; USB-B-MICRO-SMD_V03
L1, L2, L3, L4, L5, L6, L7, L8, L9, L10, L11, L12, L13, L14, L15, L16: 1.0uH; INDUCTOR-SRP4020
LOGO1, LOGO2, LOGO5, LOGO6, LOGO9, LOGO10, LOGO13, LOGO14, LOGO17, LOGO18, LOGO21, LOGO22, LOGO25, LOGO26, LOGO29, LOGO30, LOGO33, LOGO34, LOGO37, LOGO38, LOGO41, LOGO42, LOGO45, LOGO46, LOGO49, LOGO50, LOGO53, LOGO54, LOGO57, LOGO58, LOGO61, LOGO62: OSHW-LOGOS; OSHW-LOGO-S
LOGO3, LOGO8, LOGO12, LOGO16, LOGO20, LOGO24, LOGO28, LOGO32, LOGO36, LOGO40, LOGO44, LOGO48, LOGO52, LOGO56, LOGO60, LOGO64: SFE_LOGO_FLAME.2_INCH; SFE_LOGO_FLAME_.2
LOGO4, LOGO7, LOGO11, LOGO15, LOGO19, LOGO23, LOGO27, LOGO31, LOGO35, LOGO39, LOGO43, LOGO47, LOGO51, LOGO55, LOGO59, LOGO63: SFE_LOGO_NAME_FLAME.1_INCH; SFE_LOGO_NAME_FLAME_.1
Q1, Q2, Q3, Q4, Q5, Q6, Q7, Q8, Q9, Q10, Q11, Q12, Q13, Q14, Q15, Q16: 200mA/50V; SOT23-3
R1, R2, R9, R12, R13, R20, R23, R24, R31, R34, R35, R42, R45, R46, R53, R56, R57, R64, R67, R68, R75, R78, R79, R86, R89, R90, R97, R100, R101, R108, R111, R112, R119, R122, R123, R130, R133, R134, R141, R144, R145, R152, R155, R156, R163, R166, R167, R174: 10K; 0603-RES
R3, R14, R25, R36, R47, R58, R69, R80, R91, R102, R113, R124, R135, R146, R157, R168: 200k; 0603-RES
R4, R5, R15, R16, R26, R27, R37, R38, R48, R49, R59, R60, R70, R71, R81, R82, R92, R93, R103, R104, R114, R115, R125, R126, R136, R137, R147, R148, R158, R159, R169, R170: DNP; 0603-RES
R6, R11, R17, R22, R28, R33, R39, R44, R50, R55, R61, R66, R72, R77, R83, R88, R94, R99, R105, R110, R116, R121, R127, R132, R138, R143, R149, R154, R160, R165, R171, R176: 1K; 0603-RES
R7, R18, R29, R40, R51, R62, R73, R84, R95, R106, R117, R128, R139, R150, R161, R172: 680k; 0603-RES
R8, R19, R30, R41, R52, R63, R74, R85, R96, R107, R118, R129, R140, R151, R162, R173: 120k; 0603-RES
R10, R21, R32, R43, R54, R65, R76, R87, R98, R109, R120, R131, R142, R153, R164, R175: 220; 0603-RES
S1, S2, S3, S4, S5, S6, S7, S8, S9, S10, S11, S12, S13, S14, S15, S16: POWER; TACTILE_SWITCH-SMD-RIGHT-ANGLE
SJ1, SJ5, SJ8, SJ11, SJ14, SJ17, SJ20, SJ23, SJ26, SJ29, SJ32, SJ35, SJ38, SJ41, SJ44, SJ47: JUMPER-PAD-2-NOYES_SILK; PAD-JUMPER-2-NO_YES_SILK
SJ2, SJ6, SJ9, SJ12, SJ15, SJ18, SJ21, SJ24, SJ27, SJ30, SJ33, SJ36, SJ39, SJ42, SJ45, SJ48: JUMPER-PAD-3-NC_BY_PASTE; PAD-JUMPER-3-NC_BY_PASTE_YES_SILK_FULL_BOX
SJ3, SJ4, SJ7, SJ10, SJ13, SJ16, SJ19, SJ22, SJ25, SJ28, SJ31, SJ34, SJ37, SJ40, SJ43, SJ46: JUMPER-PAD-2-NC_BY_TRACE; PAD-JUMPER-2-NC_BY_TRACE_YES_SILK
TP1, TP2, TP3, TP4, TP5, TP6, TP7, TP8, TP9, TP10, TP11, TP12, TP13, TP14, TP15, TP16: TEST-POINT3X5; PAD.03X.05
U1, U10, U17, U24, U31, U38, U45, U52, U59, U66, U73, U80, U87, U94, U101, U108: PCA9306; PCA9306DC-1:1
U2, U8, U15, U22, U29, U36, U43, U50, U57, U64, U71, U78, U85, U92, U99, U106: EDISON_CONNECTOR_FULLMOUNTING_HOLES; EDISON_DAUGHTER
U3, U9, U16, U23, U30, U37, U44, U51, U58, U65, U72, U79, U86, U93, U100, U107: EDISON_CONNECTOR_FULLHEADER; DF40C-70DP-0.4(51)
U4, U11, U18, U25, U32, U39, U46, U53, U60, U67, U74, U81, U88, U95, U102, U109: TPS62065; WSON-8-PAD
U5, U12, U19, U26, U33, U40, U47, U54, U61, U68, U75, U82, U89, U96, U103, U110: MIC5219 3.3V; SOT23-5
U6, U7, U13, U14, U20, U21, U27, U28, U34, U35, U41, U42, U48, U49, U55, U56, U62, U63, U69, U70, U76, U77, U83, U84, U90, U91, U97, U98, U104, U105, U111, U112: TXB0108; UFDFN-20

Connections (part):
1.8V: C1.1, C5.1, C7.1, R4.2, R5.2, U1.1, U2.12, U3.12, U6.5, U6.6, U7.5, U7.6
1.8V1: C15.1, C21.1, C23.1, R15.2, R16.2, U8.12, U9.12, U10.1, U13.5, U13.6, U14.5, U14.6
1.8V2: C28.1, C34.1, C36.1, R26.2, R27.2, U15.12, U16.12, U17.1, U20.5, U20.6, U21.5, U21.6
1.8V3: C41.1, C47.1, C49.1, R37.2, R38.2, U22.12, U23.12, U24.1, U27.5, U27.6, U28.5, U28.6
1.8V4: C54.1, C60.1, C62.1, R48.2, R49.2, U29.12, U30.12, U31.1, U34.5, U34.6, U35.5, U35.6
1.8V5: C67.1, C73.1, C75.1, R59.2, R60.2, U36.12, U37.12, U38.1, U41.5, U41.6, U42.5, U42.6
1.8V6: C80.1, C86.1, C88.1, R70.2, R71.2, U43.12, U44.12, U45.1, U48.5, U48.6, U49.5, U49.6
1.8V7: C93.1, C99.1, C101.1, R81.2, R82.2, U50.12, U51.12, U52.1, U55.5, U55.6, U56.5, U56.6
1.8V8: C106.1, C112.1, C114.1, R92.2, R93.2, U57.12, U58.12, U59.1, U62.5, U62.6, U63.5, U63.6
1.8V9: C119.1, C125.1, C127.1, R103.2, R104.2, U64.12, U65.12, U66.1, U69.5, U69.6, U70.5, U70.6
1.8V10: C132.1, C138.1, C140.1, R114.2, R115.2, U71.12, U72.12, U73.1, U76.5, U76.6, U77.5, U77.6
1.8V11: C145.1, C151.1, C153.1, R125.2, R126.2, U78.12, U79.12, U80.1, U83.5, U83.6, U84.5, U84.6
1.8V12: C158.1, C164.1, C166.1, R136.2, R137.2, U85.12, U86.12, U87.1, U90.5, U90.6, U91.5, U91.6
1.8V13: C171.1, C177.1, C179.1, R147.2, R148.2, U92.12, U93.12, U94.1, U97.5, U97.6, U98.5, U98.6
1.8V14: C184.1, C190.1, C192.1, R158.2, R159.2, U99.12, U100.12, U101.1, U104.5, U104.6, U105.5, U105.6
1.8V15: C197.1, C203.1, C205.1, R169.2, R170.2, U106.12, U107.12, U108.1, U111.5, U111.6, U112.5, U112.6
3.3V: U2.8, U2.10, U3.8, U3.10
3.3V1: U8.8, U8.10, U9.8, U9.10
3.3V2: U15.8, U15.10, U16.8, U16.10
3.3V3: U22.8, U22.10, U23.8, U23.10
3.3V4: U29.8, U29.10, U30.8, U30.10
3.3V5: U36.8, U36.10, U37.8, U37.10
3.3V6: U43.8, U43.10, U44.8, U44.10
3.3V7: U50.8, U50.10, U51.8, U51.10
3.3V8: U57.8, U57.10, U58.8, U58.10
3.3V9: U64.8, U64.10, U65.8, U65.10
3.3V10: U71.8, U71.10, U72.8, U72.10
3.3V11: U78.8, U78.10, U79.8, U79.10
3.3V12: U85.8, U85.10, U86.8, U86.10
3.3V13: U92.8, U92.10, U93.8, U93.10
3.3V14: U99.8, U99.10, U100.8, U100.10
3.3V15: U106.8, U106.10, U107.8, U107.10
3.3V_LOCAL: C2.1, C3.1, C4.1, C6.1, C11.1, C13.1, JP1.1, JP1.17, R3.2, SJ2.2, U5.5, U6.16, U7.16
3.3V_LOCAL1: C14.1, C19.1, C20.1, C22.1, C24.1, C26.1, JP2.1, JP2.17, R14.2, SJ6.2, U12.5, U13.16, U14.16
3.3V_LOCAL2: C27.1, C32.1, C33.1, C35.1, C37.1, C39.1, JP5.1, JP5.17, R25.2, SJ9.2, U19.5, U20.16, U21.16
3.3V_LOCAL3: C40.1, C45.1, C46.1, C48.1, C50.1, C52.1, JP7.1, JP7.17, R36.2, SJ12.2, U26.5, U27.16, U28.16
3.3V_LOCAL4: C53.1, C58.1, C59.1, C61.1, C63.1, C65.1, JP9.1, JP9.17, R47.2, SJ15.2, U33.5, U34.16, U35.16
3.3V_LOCAL5: C66.1, C71.1, C72.1, C74.1, C76.1, C78.1, JP11.1, JP11.17, R58.2, SJ18.2, U40.5, U41.16, U42.16
3.3V_LOCAL6: C79.1, C84.1, C85.1, C87.1, C89.1, C91.1, JP13.1, JP13.17, R69.2, SJ21.2, U47.5, U48.16, U49.16
3.3V_LOCAL7: C92.1, C97.1, C98.1, C100.1, C102.1, C104.1, JP15.1, JP15.17, R80.2, SJ24.2, U54.5, U55.16, U56.16
3.3V_LOCAL8: C105.1, C110.1, C111.1, C113.1, C115.1, C117.1, JP17.1, JP17.17, R91.2, SJ27.2, U61.5, U62.16, U63.16
3.3V_LOCAL9: C118.1, C123.1, C124.1, C126.1, C128.1, C130.1, JP19.1, JP19.17, R102.2, SJ30.2, U68.5, U69.16, U70.16
3.3V_LOCAL10: C131.1, C136.1, C137.1, C139.1, C141.1, C143.1, JP21.1, JP21.17, R113.2, SJ33.2, U75.5, U76.16, U77.16
3.3V_LOCAL11: C144.1, C149.1, C150.1, C152.1, C154.1, C156.1, JP23.1, JP23.17, R124.2, SJ36.2, U82.5, U83.16, U84.16
3.3V_LOCAL12: C157.1, C162.1, C163.1, C165.1, C167.1, C169.1, JP25.1, JP25.17, R135.2, SJ39.2, U89.5, U90.16, U91.16
3.3V_LOCAL13: C170.1, C175.1, C176.1, C178.1, C180.1, C182.1, JP27.1, JP27.17, R146.2, SJ42.2, U96.5, U97.16, U98.16
3.3V_LOCAL14: C183.1, C188.1, C189.1, C191.1, C193.1, C195.1, JP29.1, JP29.17, R157.2, SJ45.2, U103.5, U104.16, U105.16
3.3V_LOCAL15: C196.1, C201.1, C202.1, C204.1, C206.1, C208.1, JP31.1, JP31.17, R168.2, SJ48.2, U110.5, U111.16, U112.16
5V: C10.1, C12.1, F1.2, JP1.2, JP1.4, R11.2, SJ1.1, U4.5, U4.7, U4.8
5V1: C18.1, C25.1, F2.2, JP2.2, JP2.4, R22.2, SJ5.1, U11.5, U11.7, U11.8
5V2: C31.1, C38.1, F3.2, JP5.2, JP5.4, R33.2, SJ8.1, U18.5, U18.7, U18.8
5V3: C44.1, C51.1, F4.2, JP7.2, JP7.4, R44.2, SJ11.1, U25.5, U25.7, U25.8
5V4: C57.1, C64.1, F5.2, JP9.2, JP9.4, R55.2, SJ14.1, U32.5, U32.7, U32.8
5V5: C70.1, C77.1, F6.2, JP11.2, JP11.4, R66.2, SJ17.1, U39.5, U39.7, U39.8
5V6: C83.1, C90.1, F7.2, JP13.2, JP13.4, R77.2, SJ20.1, U46.5, U46.7, U46.8
5V7: C96.1, C103.1, F8.2, JP15.2, JP15.4, R88.2, SJ23.1, U53.5, U53.7, U53.8
5V8: C109.1, C116.1, F9.2, JP17.2, JP17.4, R99.2, SJ26.1, U60.5, U60.7, U60.8
5V9: C122.1, C129.1, F10.2, JP19.2, JP19.4, R110.2, SJ29.1, U67.5, U67.7, U67.8
5V10: C135.1, C142.1, F11.2, JP21.2, JP21.4, R121.2, SJ32.1, U74.5, U74.7, U74.8
5V11: C148.1, C155.1, F12.2, JP23.2, JP23.4, R132.2, SJ35.1, U81.5, U81.7, U81.8
5V12: C161.1, C168.1, F13.2, JP25.2, JP25.4, R143.2, SJ38.1, U88.5, U88.7, U88.8
5V13: C174.1, C181.1, F14.2, JP27.2, JP27.4, R154.2, SJ41.1, U95.5, U95.7, U95.8
5V14: C187.1, C194.1, F15.2, JP29.2, JP29.4, R165.2, SJ44.1, U102.5, U102.7, U102.8
5V15: C200.1, C207.1, F16.2, JP31.2, JP31.4, R176.2, SJ47.1, U109.5, U109.7, U109.8
DCIN: Q1.2, U2.14, U3.14
DCIN1: Q2.2, U8.14, U9.14
DCIN2: Q3.2, U15.14, U16.14
DCIN3: Q4.2, U22.14, U23.14
DCIN4: Q5.2, U29.14, U30.14
DCIN5: Q6.2, U36.14, U37.14
DCIN6: Q7.2, U43.14, U44.14
DCIN7: Q8.2, U50.14, U51.14
DCIN8: Q9.2, U57.14, U58.14
DCIN9: Q10.2, U64.14, U65.14
DCIN10: Q11.2, U71.14, U72.14
DCIN11: Q12.2, U78.14, U79.14
DCIN12: Q13.2, U85.14, U86.14
DCIN13: Q14.2, U92.14, U93.14
DCIN14: Q15.2, U99.14, U100.14
DCIN15: Q16.2, U106.14, U107.14
FAULT: U2.19, U3.19
FAULT1: U8.19, U9.19
FAULT2: U15.19, U16.19
FAULT3: U22.19, U23.19
FAULT4: U29.19, U30.19
FAULT5: U36.19, U37.19
FAULT6: U43.19, U44.19
FAULT7: U50.19, U51.19
FAULT8: U57.19, U58.19
FAULT9: U64.19, U65.19
FAULT10: U71.19, U72.19
FAULT11: U78.19, U79.19
FAULT12: U85.19, U86.19
FAULT13: U92.19, U93.19
FAULT14: U99.19, U100.19
FAULT15: U106.19, U107.19
FW_RCVR: U2.69, U3.69
FW_RCVR1: U8.69, U9.69
FW_RCVR2: U15.69, U16.69
FW_RCVR3: U22.69, U23.69
FW_RCVR4: U29.69, U30.69
FW_RCVR5: U36.69, U37.69
FW_RCVR6: U43.69, U44.69
FW_RCVR7: U50.69, U51.69
FW_RCVR8: U57.69, U58.69
FW_RCVR9: U64.69, U65.69
FW_RCVR10: U71.69, U72.69
FW_RCVR11: U78.69, U79.69
FW_RCVR12: U85.69, U86.69
FW_RCVR13: U92.69, U93.69
FW_RCVR14: U99.69, U100.69
FW_RCVR15: U106.69, U107.69
GND: C1.2, C2.2, C3.2, C4.2, C5.2, C6.2, C7.2, C8.2, C10.2, C11.2, C12.2, C13.2, JP1.6, JP1.9, JP1.14, JP1.20, JP1.25, JP3.GND1, JP3.SHIELD1, JP3.SHIELD2, JP3.SHIELD3, R8.1, S1.1, SJ3.1, U1.4, U2.1, U2.5, U2.9, U2.11, U2.13, U2.15, U3.1, U3.5, U3.9, U3.11, U3.13, U3.15, U4.1, U4.3, U4.6, U4.PAD, U5.2, U6.15, U7.15
GND1: C14.2, C15.2, C16.2, C18.2, C19.2, C20.2, C21.2, C22.2, C23.2, C24.2, C25.2, C26.2, JP2.6, JP2.9, JP2.14, JP2.20, JP2.25, JP4.GND1, JP4.SHIELD1, JP4.SHIELD2, JP4.SHIELD3, R19.1, S2.1, SJ4.1, U8.1, U8.5, U8.9, U8.11, U8.13, U8.15, U9.1, U9.5, U9.9, U9.11, U9.13, U9.15, U10.4, U11.1, U11.3, U11.6, U11.PAD, U12.2, U13.15, U14.15
GND2: C27.2, C28.2, C29.2, C31.2, C32.2, C33.2, C34.2, C35.2, C36.2, C37.2, C38.2, C39.2, JP5.6, JP5.9, JP5.14, JP5.20, JP5.25, JP6.GND1, JP6.SHIELD1, JP6.SHIELD2, JP6.SHIELD3, R30.1, S3.1, SJ7.1, U15.1, U15.5, U15.9, U15.11, U15.13, U15.15, U16.1, U16.5, U16.9, U16.11, U16.13, U16.15, U17.4, U18.1, U18.3, U18.6, U18.PAD, U19.2, U20.15, U21.15
GND3: C40.2, C41.2, C42.2, C44.2, C45.2, C46.2, C47.2, C48.2, C49.2, C50.2, C51.2, C52.2, JP7.6, JP7.9, JP7.14, JP7.20, JP7.25, JP8.GND1, JP8.SHIELD1, JP8.SHIELD2, JP8.SHIELD3, R41.1, S4.1, SJ10.1, U22.1, U22.5, U22.9, U22.11, U22.13, U22.15, U23.1, U23.5, U23.9, U23.11, U23.13, U23.15, U24.4, U25.1, U25.3, U25.6, U25.PAD, U26.2, U27.15, U28.15
GND4: C53.2, C54.2, C55.2, C57.2, C58.2, C59.2, C60.2, C61.2, C62.2, C63.2, C64.2, C65.2, JP9.6, JP9.9, JP9.14, JP9.20, JP9.25, JP10.GND1, JP10.SHIELD1, JP10.SHIELD2, JP10.SHIELD3, R52.1, S5.1, SJ13.1, U29.1, U29.5, U29.9, U29.11, U29.13, U29.15, U30.1, U30.5, U30.9, U30.11, U30.13, U30.15, U31.4, U32.1, U32.3, U32.6, U32.PAD, U33.2, U34.15, U35.15
GND5: C66.2, C67.2, C68.2, C70.2, C71.2, C72.2, C73.2, C74.2, C75.2, C76.2, C77.2, C78.2, JP11.6, JP11.9, JP11.14, JP11.20, JP11.25, JP12.GND1, JP12.SHIELD1, JP12.SHIELD2, JP12.SHIELD3, R63.1, S6.1, SJ16.1, U36.1, U36.5, U36.9, U36.11, U36.13, U36.15, U37.1, U37.5, U37.9, U37.11, U37.13, U37.15, U38.4, U39.1, U39.3, U39.6, U39.PAD, U40.2, U41.15, U42.15
GND6: C79.2, C80.2, C81.2, C83.2, C84.2, C85.2, C86.2, C87.2, C88.2, C89.2, C90.2, C91.2, JP13.6, JP13.9, JP13.14, JP13.20, JP13.25, JP14.GND1, JP14.SHIELD1, JP14.SHIELD2, JP14.SHIELD3, R74.1, S7.1, SJ19.1, U43.1, U43.5, U43.9, U43.11, U43.13, U43.15, U44.1, U44.5, U44.9, U44.11, U44.13, U44.15, U45.4, U46.1, U46.3, U46.6, U46.PAD, U47.2, U48.15, U49.15
GND7: C92.2, C93.2, C94.2, C96.2, C97.2, C98.2, C99.2, C100.2, C101.2, C102.2, C103.2, C104.2, JP15.6, JP15.9, JP15.14, JP15.20, JP15.25, JP16.GND1, JP16.SHIELD1, JP16.SHIELD2, JP16.SHIELD3, R85.1, S8.1, SJ22.1, U50.1, U50.5, U50.9, U50.11, U50.13, U50.15, U51.1, U51.5, U51.9, U51.11, U51.13, U51.15, U52.4, U53.1, U53.3, U53.6, U53.PAD, U54.2, U55.15, U56.15
GND8: C105.2, C106.2, C107.2, C109.2, C110.2, C111.2, C112.2, C113.2, C114.2, C115.2, C116.2, C117.2, JP17.6, JP17.9, JP17.14, JP17.20, JP17.25, JP18.GND1, JP18.SHIELD1, JP18.SHIELD2, JP18.SHIELD3, R96.1, S9.1, SJ25.1, U57.1, U57.5, U57.9, U57.11, U57.13, U57.15, U58.1, U58.5, U58.9, U58.11, U58.13, U58.15, U59.4, U60.1, U60.3, U60.6, U60.PAD, U61.2, U62.15, U63.15
GND9: C118.2, C119.2, C120.2, C122.2, C123.2, C124.2, C125.2, C126.2, C127.2, C128.2, C129.2, C130.2, JP19.6, JP19.9, JP19.14, JP19.20, JP19.25, JP20.GND1, JP20.SHIELD1, JP20.SHIELD2, JP20.SHIELD3, R107.1, S10.1, SJ28.1, U64.1, U64.5, U64.9, U64.11, U64.13, U64.15, U65.1, U65.5, U65.9, U65.11, U65.13, U65.15, U66.4, U67.1, U67.3, U67.6, U67.PAD, U68.2, U69.15, U70.15
GND10: C131.2, C132.2, C133.2, C135.2, C136.2, C137.2, C138.2, C139.2, C140.2, C141.2, C142.2, C143.2, JP21.6, JP21.9, JP21.14, JP21.20, JP21.25, JP22.GND1, JP22.SHIELD1, JP22.SHIELD2, JP22.SHIELD3, R118.1, S11.1, SJ31.1, U71.1, U71.5, U71.9, U71.11, U71.13, U71.15, U72.1, U72.5, U72.9, U72.11, U72.13, U72.15, U73.4, U74.1, U74.3, U74.6, U74.PAD, U75.2, U76.15, U77.15
GND11: C144.2, C145.2, C146.2, C148.2, C149.2, C150.2, C151.2, C152.2, C153.2, C154.2, C155.2, C156.2, JP23.6, JP23.9, JP23.14, JP23.20, JP23.25, JP24.GND1, JP24.SHIELD1, JP24.SHIELD2, JP24.SHIELD3, R129.1, S12.1, SJ34.1, U78.1, U78.5, U78.9, U78.11, U78.13, U78.15, U79.1, U79.5, U79.9, U79.11, U79.13, U79.15, U80.4, U81.1, U81.3, U81.6, U81.PAD, U82.2, U83.15, U84.15
GND12: C157.2, C158.2, C159.2, C161.2, C162.2, C163.2, C164.2, C165.2, C166.2, C167.2, C168.2, C169.2, JP25.6, JP25.9, JP25.14, JP25.20, JP25.25, JP26.GND1, JP26.SHIELD1, JP26.SHIELD2, JP26.SHIELD3, R140.1, S13.1, SJ37.1, U85.1, U85.5, U85.9, U85.11, U85.13, U85.15, U86.1, U86.5, U86.9, U86.11, U86.13, U86.15, U87.4, U88.1, U88.3, U88.6, U88.PAD, U89.2, U90.15, U91.15
GND13: C170.2, C171.2, C172.2, C174.2, C175.2, C176.2, C177.2, C178.2, C179.2, C180.2, C181.2, C182.2, JP27.6, JP27.9, JP27.14, JP27.20, JP27.25, JP28.GND1, JP28.SHIELD1, JP28.SHIELD2, JP28.SHIELD3, R151.1, S14.1, SJ40.1, U92.1, U92.5, U92.9, U92.11, U92.13, U92.15, U93.1, U93.5, U93.9, U93.11, U93.13, U93.15, U94.4, U95.1, U95.3, U95.6, U95.PAD, U96.2, U97.15, U98.15
GND14: C183.2, C184.2, C185.2, C187.2, C188.2, C189.2, C190.2, C191.2, C192.2, C193.2, C194.2, C195.2, JP29.6, JP29.9, JP29.14, JP29.20, JP29.25, JP30.GND1, JP30.SHIELD1, JP30.SHIELD2, JP30.SHIELD3, R162.1, S15.1, SJ43.1, U99.1, U99.5, U99.9, U99.11, U99.13, U99.15, U100.1, U100.5, U100.9, U100.11, U100.13, U100.15, U101.4, U102.1, U102.3, U102.6, U102.PAD, U103.2, U104.15, U105.15
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

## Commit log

2014-08-11 Completed schematic.
    [edison_mezzanine_pi_breakout.brd, edison_mezzanine_pi_breakout.sch]
2014-08-11 Initial component placement.
    [edison_mezzanine_pi_breakout.brd, edison_mezzanine_pi_breakout.sch]
2014-08-12 More layout. Swapped 22 Ohm with 220 Ohm in schematic for power button.
    [edison_mezzanine_pi_breakout.brd, edison_mezzanine_pi_breakout.sch]
2014-08-12 Added more layout to Pi connector.
    [edison_mezzanine_pi_breakout.brd]
2014-08-12 More layout.
    [edison_mezzanine_pi_breakout.brd]
2014-08-13 Finished layout for prototype.
    [edison_mezzanine_pi_breakout.brd, edison_mezzanine_pi_breakout.sch]
2014-08-13 Added LED EN to silk. Enlargened section headings on schem.
    [edison_mezzanine_pi_breakout.brd, edison_mezzanine_pi_breakout.sch]
2014-09-25 Replaced Header footprint Included DCIN pin Renamed boards Renamed files Replaces power button with side shooting SMD Cleaned up dimensions
    TODO: solve power situation between VSYS and DCIN
    TODO: Add pass through via for DCIN
    [Pi_Block.brd, Pi_Block.sch]
2014-09-26 Added Vsys-to-5V diode. Added DCIN to Vsys MOSFET. Added slants to board dimension near Pi connector for stability.
    [Pi_Block.brd, Pi_Block.sch]
2014-10-10 Made R4 and R5 DNP. Added I2C PU solder jumper. Changed I2C PUs to 10k.
    [Pi_Block.brd, Pi_Block.sch]
2014-10-10 Changed value from 10k to 10K to align with library
    [Pi_Block.brd, Pi_Block.sch]
2014-10-20 Changed DC/DC output cap to 22uF. Added value to inductor.
    [Pi_Block.brd, Pi_Block.sch]
2014-12-05 Added silk to Pi pins. Moved a few traces to straighten them or prevent bridging of pins.
    [Pi_Block.brd, Pi_Block.sch]
2014-12-10 Added ICs to SF lib. Added pin markers to ICs. Changed routing of TXB and PCA to come straight out pins. Added mounting hole below header. Added notes to board.
    [Pi_Block.brd, Pi_Block.sch]
2014-12-10 Corrected errors from review and QC check (see GitHub issues)
    [Pi_Block.brd, Pi_Block.sch]
2014-12-10 Changed pin numbers in silk to GP Edison pin numbers
    [Pi_Block.brd]
2014-12-10 Fixed silk on PCA. Added dimensions.
    [Pi_Block.brd, Pi_Block.sch]
2014-12-19 created v10 panels
    [Pi_Block-GiantPanel-v10.brd, Pi_Block-Panel-v10.brd]

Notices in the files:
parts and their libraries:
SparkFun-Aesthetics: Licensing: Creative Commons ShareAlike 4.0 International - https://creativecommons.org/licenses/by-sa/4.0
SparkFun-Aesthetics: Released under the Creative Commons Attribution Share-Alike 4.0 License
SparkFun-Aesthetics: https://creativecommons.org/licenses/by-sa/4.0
